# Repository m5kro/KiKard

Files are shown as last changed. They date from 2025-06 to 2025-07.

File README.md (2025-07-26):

# KiKard
Pronounced key card. KiKard is a usb microcontroller board with NFC read, write, and tag support. Built for Hack Club Highway. Not affiliated with KiCad (but do check them out).<br>
<br>
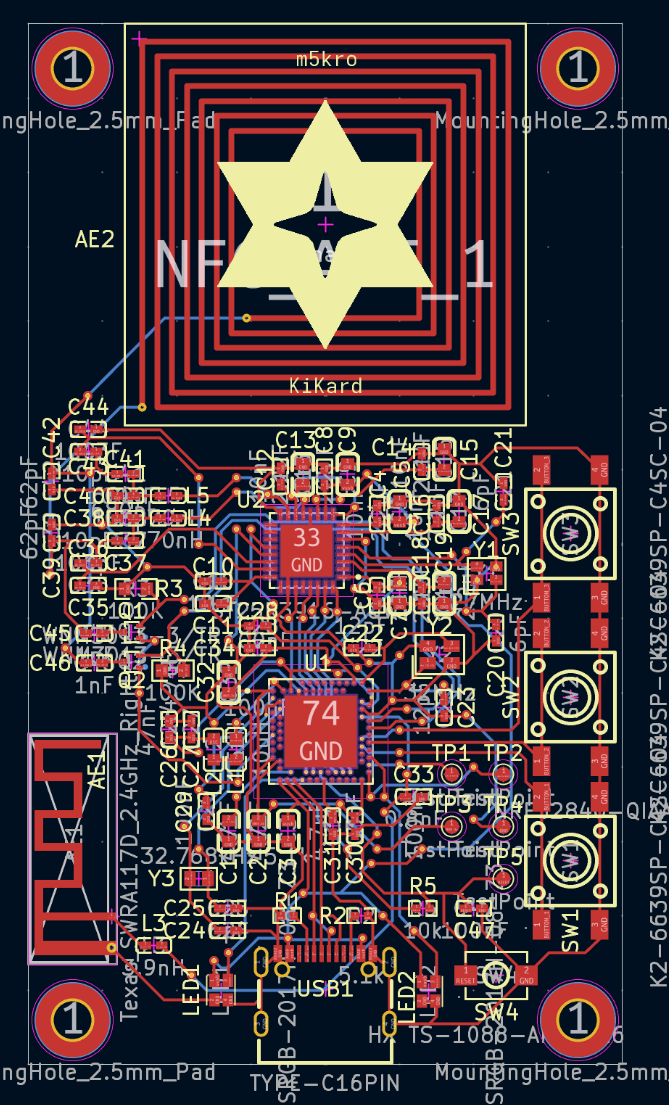
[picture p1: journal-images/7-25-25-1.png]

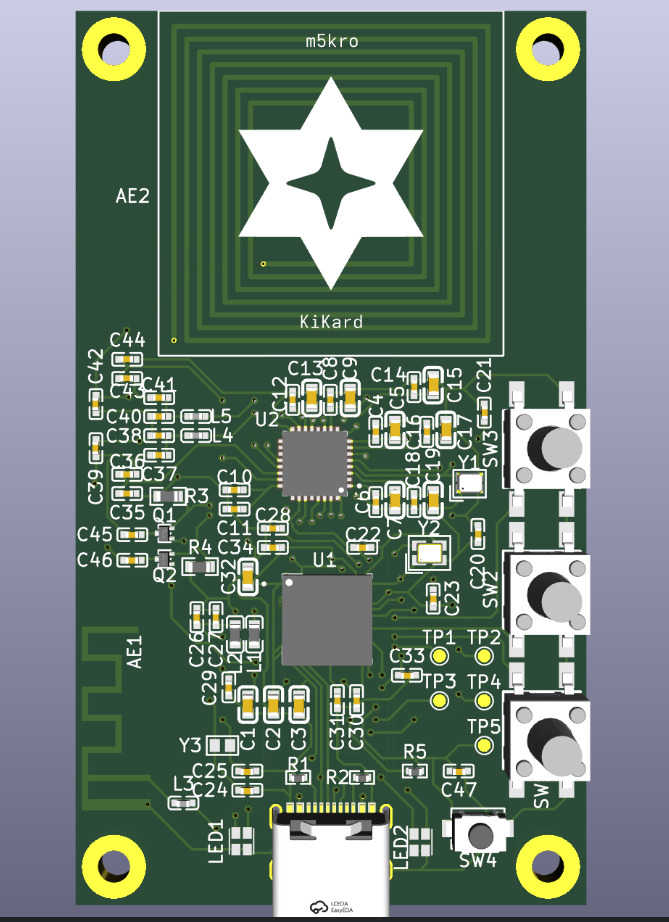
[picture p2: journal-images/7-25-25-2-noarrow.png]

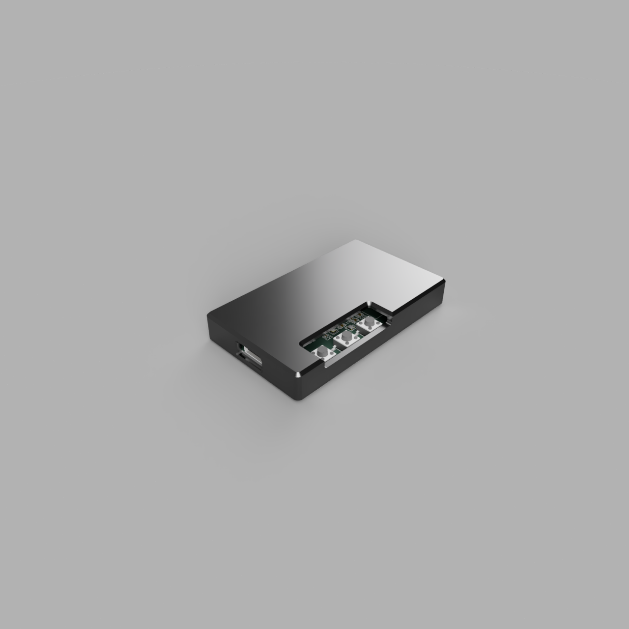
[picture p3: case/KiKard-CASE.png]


# What it does
KiKard is designed to read, write, and emulate NFC devices. This can be anything from simple link tags to complex keycards with custom communication standards. It can work independently or with a computer through BLE or USB.

# Why I built it
The goal of this project is to create a tool to assist me with my NFC application development learning. About a year ago, I wanted to make apps that utilize NFC, but I realized that most phones (most widespread implementation of NFC) are terrible for the development process as everything is very locked down. I did get a cheap PN532 reader from amazon and while it did help, it was still very lacking. Thus I decided to create KiKard to cover all the requirements needed by my other projects.

# Other Notes
Although the NRF has NFC support built in, it's only for tag mode, so a separate chip is needed for reading NFC.<br>
RGB LED 1 - Status led Green: just connected, Pink: reset/flashing, Blue: NRF52 tag mode, Yellow: ST25 read mode, Red: error<br>
RGB LED 2 - read/tag status Yellow: waiting, Blue: reading/emulating, Green: success, Red: error<br>
Button 1 - Read/emulate<br>
Button 2 - Switch between NRF52 and ST25<br>
Button 3 - Switch emulated tag (can save different cards on device)<br>
The DAPLINK is used to flash the NRF with a bootloader as it doesn't come with one by default. There are test pads on the board to connect.<br>
There are alot of extended parts as I needed high quality caps for the NFC antenna.<br>
Tariffs are making this project alot more expensive than it needs to be ;(

# Bom
| Item | Price |
| :-----: | :-----: |
| Custom PCB x5 | $4.00 |
| PCBA Setup | $8.00 |
| Stencil | $1.50 |
| PCB Parts x2| $20.07
| Extended Parts Fee | $81.00 |
| SMT Assembly | $1.86
| X-ray Inspection (required) | $3.14 |
| Nitrogen Reflow Soldering | $0.82 |
| Shipping | $28.85 |
| Customs | $66.22 |
| [DAPLINK](https://www.aliexpress.us/item/3256803753392042.html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) | $3.52 |
| JLCPCB special discount | -$2.00 |

**Total: $227.50**

# PCB Parts Bom (PER PCB)
Total PCB Parts: 71<br>
Total PCB Parts Price (per PCB): $8.7174
| Part | Designator | Quantity | Price per Unit | Total | JLCPCB/LCSC Part No. |
| :---: | :-----: | :-----: | :-----: | :-----: | :-----: |
| [NRF-52840-QIAA-R](https://jlcpcb.com/partdetail/NordicSemicon-NRF52840_QIAAR/C190794) | U1 | 1 | $4.0290 | $4.0290 | C190794 |
| [ST25R3916-AQWT](https://jlcpcb.com/partdetail/STMicroelectronics-ST25R3916AQWT/C2908147) | U2 | 1 | $3.3795 | $3.3795 | C2908147 |
| [WNM3013-3/TR](https://jlcpcb.com/partdetail/WILLSEMI_Will_Semicon-WNM3013_3TR/C239659) | Q1, Q2 | 2 | $0.0333 | $0.0667 | C239659 |
| [32MHz Crystal Oscillator](https://jlcpcb.com/partdetail/2777870-X201632MOB4SI/C2682773) | Y2 | 1 | $0.0890 | $0.0890 | C2682773 |
| [27MHz Crystal Oscillator](https://jlcpcb.com/partdetail/604049-XRCGB27M120F3M00R0/C576558) | Y1 | 1 | $0.1773 | $0.1773 | C576558 |
| [32KHz Crystal Oscillator](https://jlcpcb.com/partdetail/357119-X161032768KGD2SI/C383847) | Y3 | 1 | $0.3825 | $0.3825 | C383847 |
| [USB-C Port](https://jlcpcb.com/partdetail/SHOUHAN-TYPEC16PIN/C393939) | USB1 | 1 | $0.0642 | $0.0642 | C393939 |
| [RGBLED](https://jlcpcb.com/partdetail/ChauLight-ZSRGB_2017H_08Z3/C7497245) | LED1, LED2 | 2 | $0.0807 | $0.1614 | C7497245 |
| [Button](https://jlcpcb.com/partdetail/Korean_HropartsElec-K2_6639SP_C4SC04/C83206) | SW1, SW2, SW3 | 3 | $0.0380 | $0.1140 | C83206 |
| [Small Button](https://jlcpcb.com/partdetail/hanxia-HX_3x4x2_2P_25N/C36498961) | SW4 | 1 | $0.0299 | $0.0299 | C36498961 |
| [100k Ohm Resistor](https://jlcpcb.com/partdetail/YAGEO-RC0603FR07100KL/C14675) | R3, R4 | 2 | $0.0010 | $0.0020 | C14675 |
| [10k Ohm Resistor](https://jlcpcb.com/partdetail/26274-0402WGJ0103TCE/C25531) | R5 | 1 | $0.0004 | $0.0004 | C25531 |
| [5.1k Ohm Resistor](https://jlcpcb.com/partdetail/26684-0402WGJ0512TCE/C25941) | R1, R2 | 2 | $0.0004 | $0.0008 | C25941 |
| [4.7uF Capacitor](https://jlcpcb.com/partdetail/20375-CL10A475KO8NNNC/C19666) | C1, C2, C3, C32 | 4 | $0.0101 | $0.0404 | C19666 |
| [2.2uF Capacitor](https://jlcpcb.com/partdetail/1959-CL10A225KP8NNNC/C1607) | C5, C7, C9, C13, C15, C17, C19 | 7 | $0.0060 | $0.0420 | C1607 |
| [1uF Capacitor](https://jlcpcb.com/partdetail/15107-CL05A105KP5NNNC/C14445) | C11, C27 | 2 | $0.0016 | $0.0032 | C14445 |
| [100nF Capacitor](https://jlcpcb.com/partdetail/57421-0402B104K250NT/C56392) | C28, C29, C30, C31, C34, C47 | 6 |  $0.0011 |  $0.0066 | C56392 |
| [47nF Capacitor](https://jlcpcb.com/partdetail/83376-0402B473K500NT/C82219) | C26 | 1 | $0.0017 | $0.0017 | C82219 |
| [10nF Capacitor](https://jlcpcb.com/partdetail/1876-0402B103K500NT/C1524) | C4, C6, C8, C10, C12, C14, C16, C18 | 8 | $0.0010 | $0.0080 | C1524 |
| [1nF Capacitor](https://jlcpcb.com/partdetail/TDK-C1005C0G1E102JT000F/C343059) | C45, C46 | 2 | $0.0089 | $0.0178 | C343059 |
| [680pF Capacitor](https://jlcpcb.com/partdetail/1893-0402B681K500NT/C1541) | C38, C40 | 2 | $0.0011 | $0.0022 | C1541 |
| [100pF Capacitor](https://jlcpcb.com/partdetail/1898-0402CG101J500NT/C1546) | C35, C37, C41, C44 | 4 | $0.0089 | $0.0356 | C1546 |
| [62pF Capacitor](https://jlcpcb.com/partdetail/YAGEO-CC0402JRNPO9BN620/C281763) | C39, C42 | 2 | $0.0014 | $0.0028 | C281763 |
| [12pF Capacitor](https://jlcpcb.com/partdetail/1899-0402CG120J500NT/C1547) | C22, C23 | 2 | $0.0010 | $0.0020 | C1547 |
| [10pF Capacitor](https://jlcpcb.com/partdetail/1897-0402CG100J500NT/C1545) | C36, C43 | 2 | $0.0010 | $0.0020 | C1545 |
| [6pF Capacitor](https://jlcpcb.com/partdetail/1927-0402CG6R0C500NT/C1575) | C20, C21, C24, C25 | 4 | $0.0010 | $0.0040 | C1575 |
| [0.8pF Capacitor](https://jlcpcb.com/partdetail/41442-0402CG0R8C500NT/C40459) | C33 | 1 | $0.0013 | $0.0013 | C40459 |
| [10uH Inductor](https://jlcpcb.com/partdetail/Sunlord-MCL1608S100MT/C51942) | L1 | 1 | $0.0212 | $0.0212 | C51942 |
| [270nH Inductor](https://jlcpcb.com/partdetail/TDK-MLG1005SR27JT000/C76784) | L4, L5 | 2 | $0.0077 | $0.0154 | C76784 |
| [15nH Inductor](https://jlcpcb.com/partdetail/Sunlord-SDCL1608C15NJTDF/C23651) | L2 | 1 | $0.0106 | $0.0106 | C23651 |
| [3.9nH Inductor](https://jlcpcb.com/partdetail/Sunlord-SDCL1005C3N9STDF/C14033) | L3 | 1 | $0.0039 | $0.0039 | C14033 |

# Credit
[NRF-52840-QIAA-R schematic and footprint was aquired from snapeda](https://www.snapeda.com/parts/NRF52840-QIAA-R/Nordic%20Power/view-part/)<br>
[ST25R3916-AQWT schematic and footprint was aquired from snapeda](https://www.snapeda.com/parts/ST25R3916-AQWT/STMicroelectronics/view-part/)<br>
[NFC antenna footprint created using nfc antenna generator by nideri](https://github.com/nideri/nfc_antenna_generator)

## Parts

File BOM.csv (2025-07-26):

Item | Price | Link
Custom PCB x5 | 4 | /hardware
PCBA Setup | 8
Stencil | 1.5
PCB Parts x2 | 20.07 | /PCB-BOM.csv
Extended Parts Fee | 81
SMT Assembly | 1.86
X-ray Inspection (required) | 3.14
Nitrogen Reflow Soldering | 0.82
Shipping | 28.85
Customs | 66.22
DAPLINK | 3.52 | https://www.aliexpress.us/item/3256803753392042.html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
JLCPCB special discount | -2
Total | 227.50

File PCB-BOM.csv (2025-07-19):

Part | Designator | Quantity | Price per Unit | Total | JLCPCB/LCSC Part No. | Link
NRF-52840-QIAA-R | U1 | 1 | 4.0290 | 4.0290 | C190794 | https://jlcpcb.com/partdetail/NordicSemicon-NRF52840_QIAAR/C190794
ST25R3916-AQWT | U2 | 1 | 3.3795 | 3.3795 | C2908147 | https://jlcpcb.com/partdetail/STMicroelectronics-ST25R3916AQWT/C2908147
WNM3013-3/TR | Q1, Q2 | 2 | 0.0333 | 0.0667 | C239659 | https://jlcpcb.com/partdetail/WILLSEMI_Will_Semicon-WNM3013_3TR/C239659
32MHz Crystal Oscillator | Y2 | 1 | 0.0890 | 0.0890 | C2682773 | https://jlcpcb.com/partdetail/2777870-X201632MOB4SI/C2682773
27MHz Crystal Oscillator | Y1 | 1 | 0.1773 | 0.1773 | C576558 | https://jlcpcb.com/partdetail/604049-XRCGB27M120F3M00R0/C576558
32KHz Crystal Oscillator | Y3 | 1 | 0.3825 | 0.3825 | C383847 | https://jlcpcb.com/partdetail/357119-X161032768KGD2SI/C383847
USB-C Port | USB1 | 1 | 0.0642 | 0.0642 | C393939 | https://jlcpcb.com/partdetail/SHOUHAN-TYPEC16PIN/C393939
RGBLED | LED1, LED2 | 2 | 0.0807 | 0.1614 | C7497245 | https://jlcpcb.com/partdetail/ChauLight-ZSRGB_2017H_08Z3/C7497245
Button | SW1, SW2, SW3 | 3 | 0.0380 | 0.1140 | C83206 | https://jlcpcb.com/partdetail/Korean_HropartsElec-K2_6639SP_C4SC04/C83206
Small Button | SW4 | 1 | 0.0299 | 0.0299 | C36498961 | https://jlcpcb.com/partdetail/hanxia-HX_3x4x2_2P_25N/C36498961
100k Ohm Resistor | R3, R4 | 2 | 0.0010 | 0.0020 | C14675 | https://jlcpcb.com/partdetail/YAGEO-RC0603FR07100KL/C14675
10k Ohm Resistor | R5 | 1 | 0.0004 | 0.0004 | C25531 | https://jlcpcb.com/partdetail/26274-0402WGJ0103TCE/C25531
5.1k Ohm Resistor | R1, R2 | 2 | 0.0004 | 0.0008 | C25941 | https://jlcpcb.com/partdetail/26684-0402WGJ0512TCE/C25941
4.7uF Capacitor | C1, C2, C3, C32 | 4 | 0.0101 | 0.0404 | C19666 | https://jlcpcb.com/partdetail/20375-CL10A475KO8NNNC/C19666
2.2uF Capacitor | C5, C7, C9, C13, C15, C17, C19 | 7 | 0.0060 | 0.0420 | C1607 | https://jlcpcb.com/partdetail/1959-CL10A225KP8NNNC/C1607
1uF Capacitor | C11, C27 | 2 | 0.0016 | 0.0032 | C14445 | https://jlcpcb.com/partdetail/15107-CL05A105KP5NNNC/C14445
100nF Capacitor | C28, C29, C30, C31, C34, C47 | 6 | 0.0011 | 0.0066 | C56392 | https://jlcpcb.com/partdetail/57421-0402B104K250NT/C56392
47nF Capacitor | C26 | 1 | 0.0017 | 0.0017 | C82219 | https://jlcpcb.com/partdetail/83376-0402B473K500NT/C82219
10nF Capacitor | C4, C6, C8, C10, C12, C14, C16, C18 | 8 | 0.0010 | 0.0080 | C1524 | https://jlcpcb.com/partdetail/1876-0402B103K500NT/C1524
1nF Capacitor | C45, C46 | 2 | 0.0089 | 0.0178 | C343059 | https://jlcpcb.com/partdetail/TDK-C1005C0G1E102JT000F/C343059
680pF Capacitor | C38, C40 | 2 | 0.0011 | 0.0022 | C1541 | https://jlcpcb.com/partdetail/1893-0402B681K500NT/C1541
100pF Capacitor | C35, C37, C41, C44 | 4 | 0.0089 | 0.0356 | C1546 | https://jlcpcb.com/partdetail/1898-0402CG101J500NT/C1546
62pF Capacitor | C39, C42 | 2 | 0.0014 | 0.0028 | C281763 | https://jlcpcb.com/partdetail/YAGEO-CC0402JRNPO9BN620/C281763
12pF Capacitor | C22, C23 | 2 | 0.0010 | 0.0020 | C1547 | https://jlcpcb.com/partdetail/1899-0402CG120J500NT/C1547
10pF Capacitor | C36, C43 | 2 | 0.0010 | 0.0020 | C1545 | https://jlcpcb.com/partdetail/1897-0402CG100J500NT/C1545
6pF Capacitor | C20, C21, C24, C25 | 4 | 0.0010 | 0.0040 | C1575 | https://jlcpcb.com/partdetail/1927-0402CG6R0C500NT/C1575
0.8pF Capacitor | C33 | 1 | 0.0013 | 0.0013 | C40459 | https://jlcpcb.com/partdetail/41442-0402CG0R8C500NT/C40459
10uH Inductor | L1 | 1 | 0.0212 | 0.0212 | C51942 | https://jlcpcb.com/partdetail/Sunlord-MCL1608S100MT/C51942
270nH Inductor | L4, L5 | 2 | 0.0077 | 0.0154 | C76784 | https://jlcpcb.com/partdetail/TDK-MLG1005SR27JT000/C76784
15nH Inductor | L2 | 1 | 0.0106 | 0.0106 | C23651 | https://jlcpcb.com/partdetail/Sunlord-SDCL1608C15NJTDF/C23651
3.9nH Inductor | L3 | 1 | 0.0039 | 0.0039 | C14033 | https://jlcpcb.com/partdetail/Sunlord-SDCL1005C3N9STDF/C14033

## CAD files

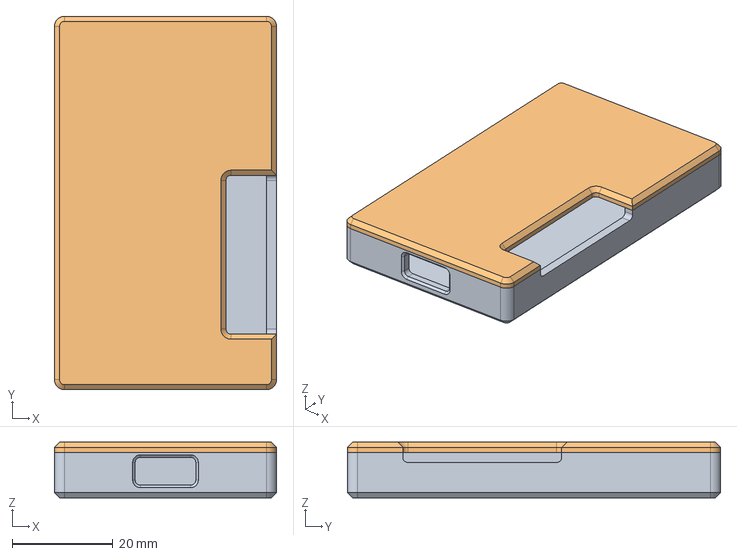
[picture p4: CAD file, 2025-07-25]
case/KiKard-Case.step
44.0 x 74.0 x 11.0 mm

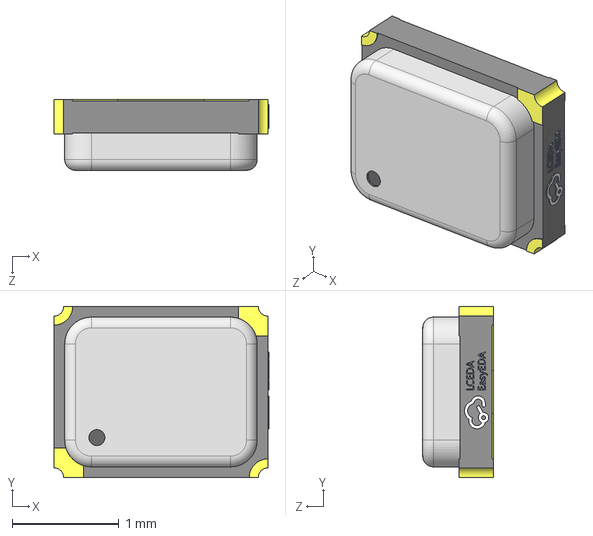
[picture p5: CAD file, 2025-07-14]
hardware/extra-symbols-footprints/3dshapes/CRYSTAL-SMD_4P-L2.0-W1.6-BL-B.step
2.01 x 1.60 x 0.66 mm

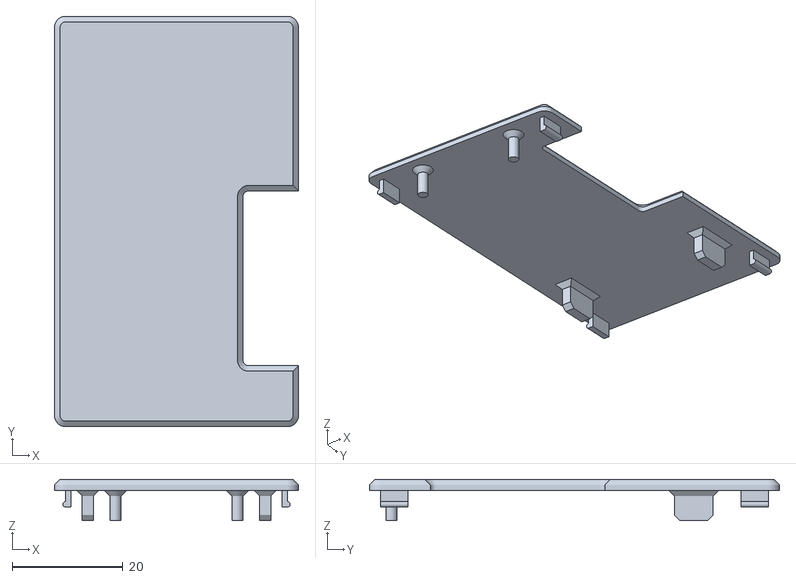
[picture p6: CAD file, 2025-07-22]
production/KiKard-Case-Top.stl
44.0 x 74.0 x 7.44

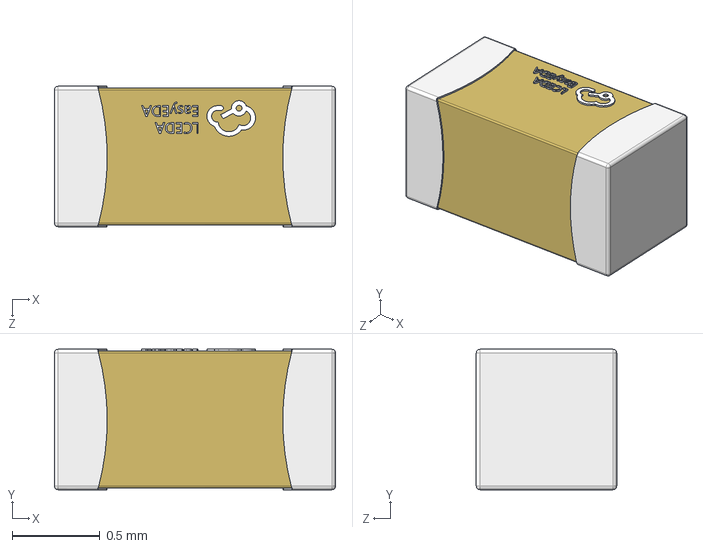
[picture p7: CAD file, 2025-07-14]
hardware/extra-symbols-footprints/3dshapes/C0603_L1.6-W0.8-H0.8.step
1.60 x 0.8 x 0.8 mm

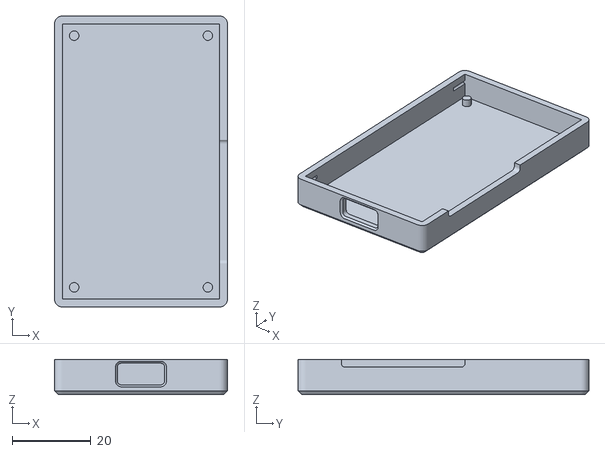
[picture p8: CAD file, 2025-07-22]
production/KiKard-Case-Base.stl
44.0 x 74.0 x 9.00

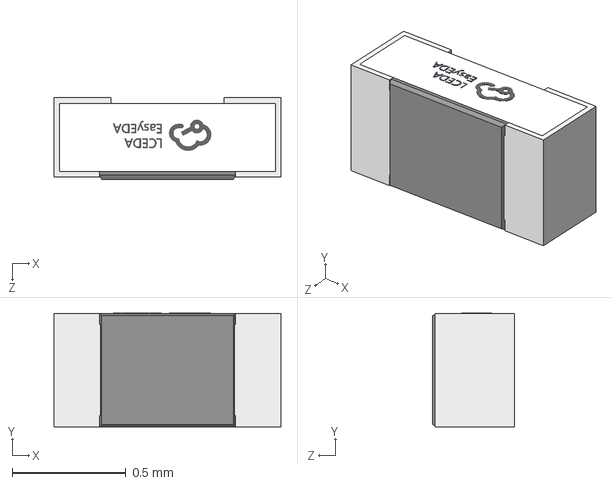
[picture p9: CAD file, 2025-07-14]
hardware/extra-symbols-footprints/3dshapes/R0402_L1.0-W0.5-H0.4.step
1.00 x 0.501 x 0.36 mm

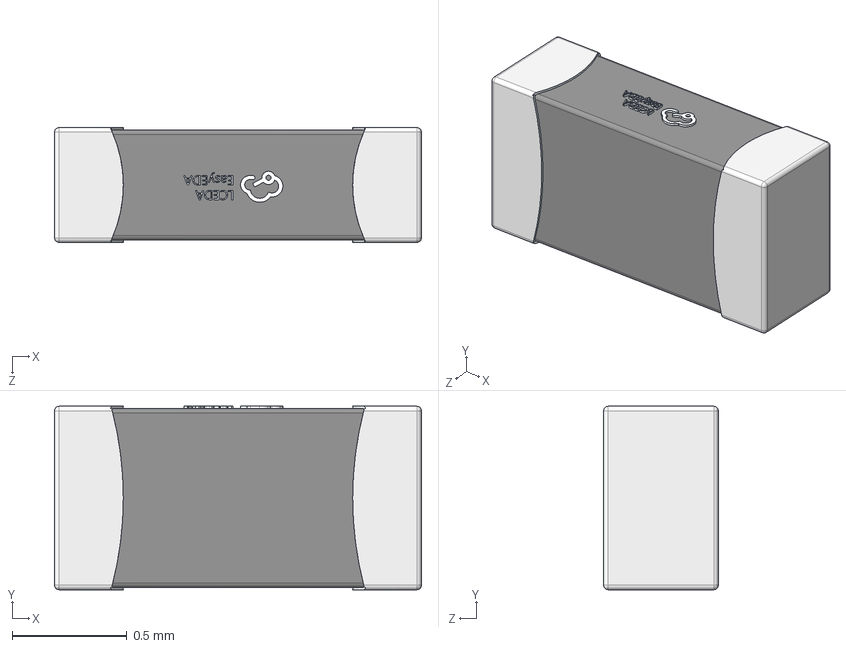
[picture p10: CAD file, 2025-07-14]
hardware/extra-symbols-footprints/3dshapes/L0603_L1.6-W0.8-H0.5_BEAD.step
1.60 x 0.8 x 0.5 mm

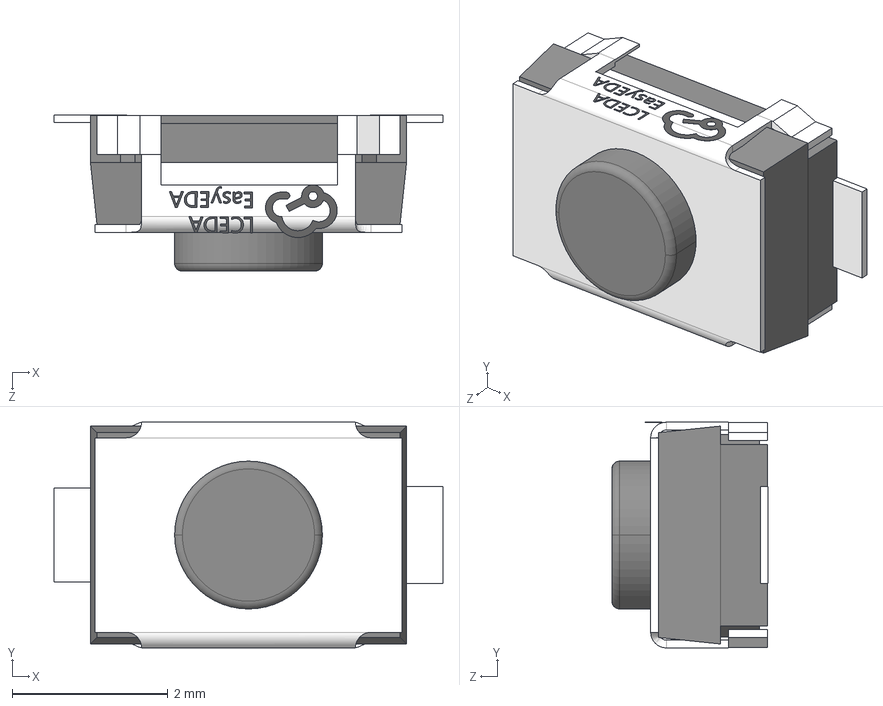
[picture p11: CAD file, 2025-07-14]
hardware/extra-symbols-footprints/3dshapes/SW-SMD_L4.0-W2.9-H2-LS5.0.step
5.00 x 2.90 x 2.01 mm

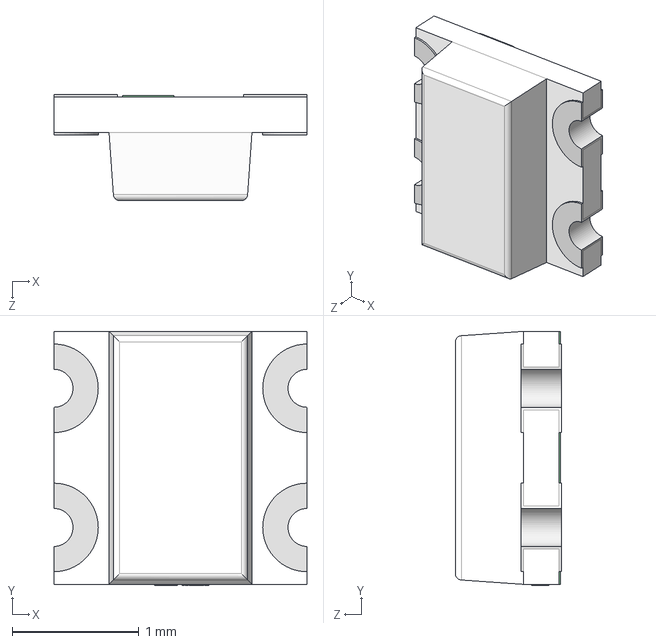
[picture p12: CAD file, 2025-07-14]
hardware/extra-symbols-footprints/3dshapes/LED-SMD_4P-L2.0-W2.0-H0.8-TL_WS2812B-2020.step
2.00 x 2.01 x 0.84 mm

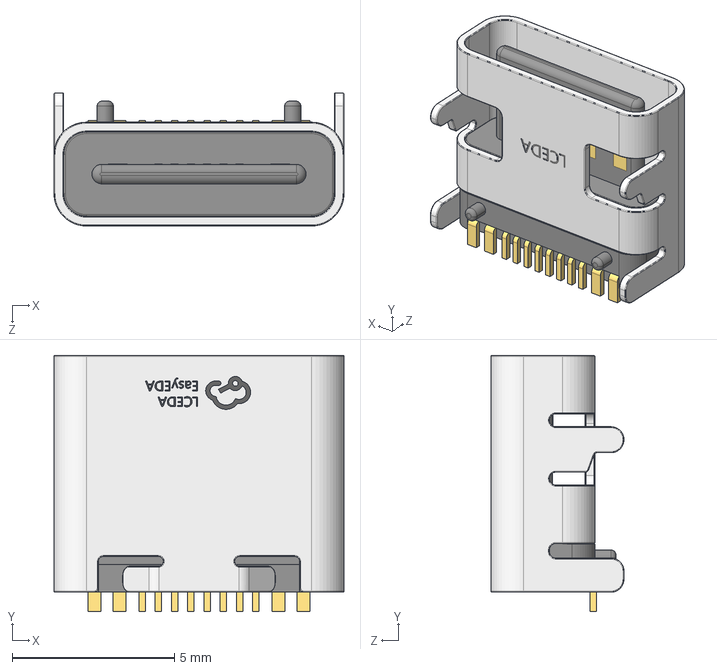
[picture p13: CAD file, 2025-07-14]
hardware/extra-symbols-footprints/3dshapes/USB-C-SMD_TYPE-C16PIN.step
8.94 x 7.90 x 4.10 mm

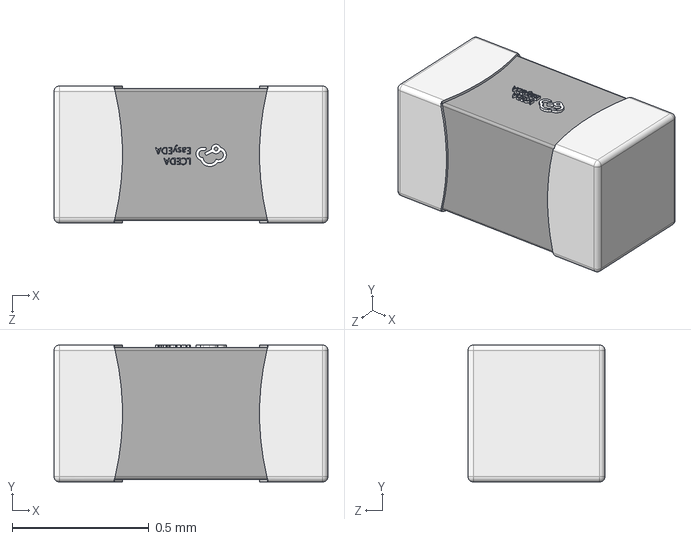
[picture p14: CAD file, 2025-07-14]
hardware/extra-symbols-footprints/3dshapes/L0402_L1.0-W0.5-H0.5_BEAD.step
1.00 x 0.5 x 0.5 mm

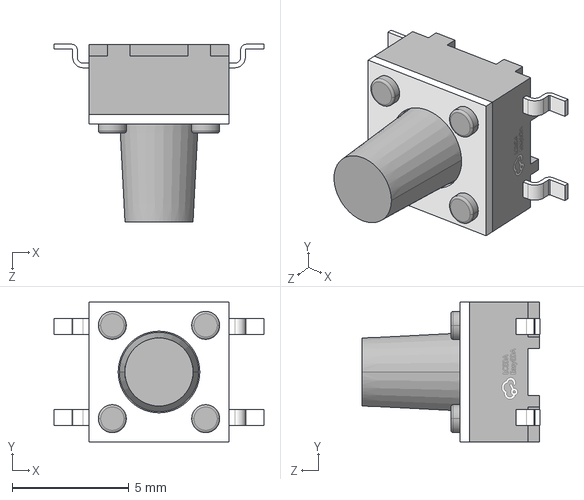
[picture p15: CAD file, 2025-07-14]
hardware/extra-symbols-footprints/3dshapes/KEY-SMD_4P-L6.0-W6.0-H8.0-P3.90-LS9.0.step
9.00 x 6.00 x 7.61 mm

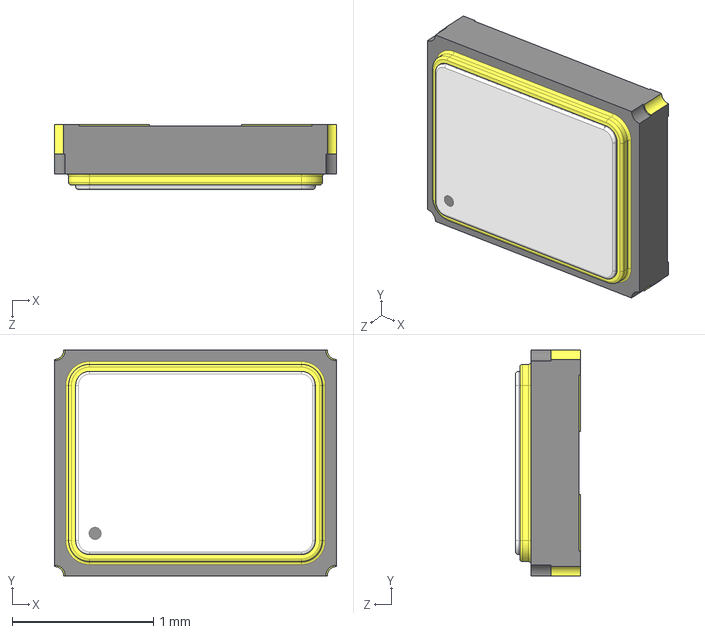
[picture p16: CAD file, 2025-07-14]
hardware/extra-symbols-footprints/3dshapes/CRYSTAL-SMD_4P-L2.0-W1.6-BL-2.step
2.00 x 1.60 x 0.46 mm

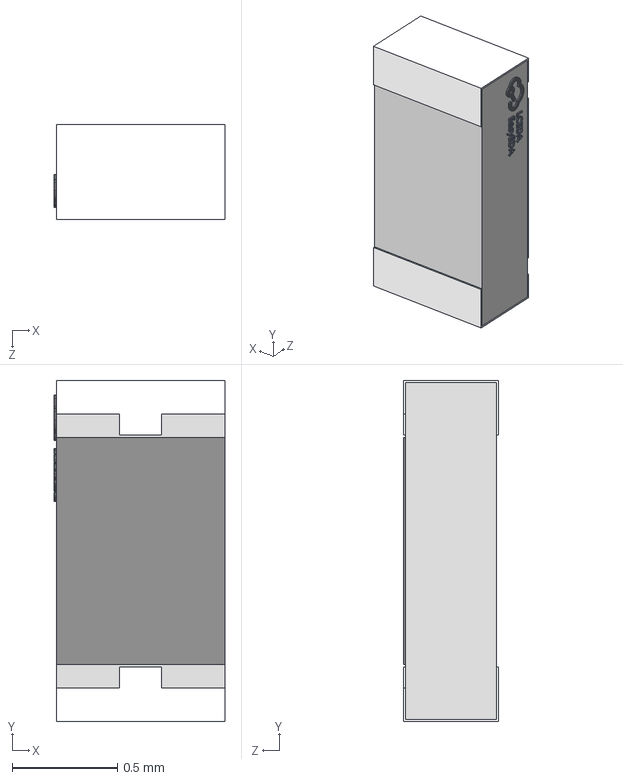
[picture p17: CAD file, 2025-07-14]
hardware/extra-symbols-footprints/3dshapes/R0603.step
0.81 x 1.62 x 0.45 mm

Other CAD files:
hardware/extra-symbols-footprints/3dshapes/C0402_L1.0-W0.5-H0.5.step
hardware/extra-symbols-footprints/3dshapes/SOT-723-3P_L1.2-W0.8-H0.6-LS1.2-P0.40.step
hardware/extra-symbols-footprints/3dshapes/ST25R3916-AQWT.step
hardware/extra-symbols-footprints/3dshapes/NRF52840-QIAA-R.step

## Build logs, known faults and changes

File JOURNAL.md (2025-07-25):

---
title: "KiKard"
author: "m5kro"
description: "A usb microcontroller board with NFC read, write, and tag support."
created_at: "2025-06-1"
---
# Total Time
50 hours

## 6/1/25 
Came up with the initial idea and some basic plans. I did research on the NRF-52 series and found out that it alone wasn't sufficient for what I wanted to build, so I needed a separate chip. After searching online, I found that the PN532 was a popular choice since it was cheap and widely available, but the PN533 might have more features. <br>
<br>
Since I settled on using the NRF-52840-QIAA-R as the main microcontroller I created a new KiCad project and imported the schematic and footprint.<br>
<br>
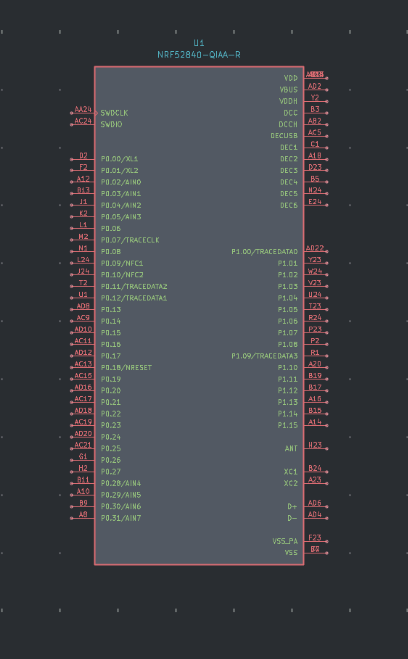
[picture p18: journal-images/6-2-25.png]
<br>
Screenshot of KiCad NRF-52840-QIAA-R schematic
<br>
<br>
**Time spent today: 2h**<br>
**Total time spent: 2h**
## 6/4/25
After further research and looking at what JLCPCB has, the ST25R3916-AQWT may be a better pick for the reader chip. It's cheaper than the PN532, a bit newer, and can do a bit more too. Although it is capable of tag emulation, it doesn't seem as capable as the NRF52, so a dual chip setup is still needed. <br>
<br>
A future problem I will need to deal with is the antenna setup. I will need a way to connect both chips to the antennas using a switching method so there isn't any interference.<br>
<br>
In KiCad, I imported the ST25R3916-AQWT symbol and schematic and connected up the NRF52 to a USB-C port.<br>
<br>
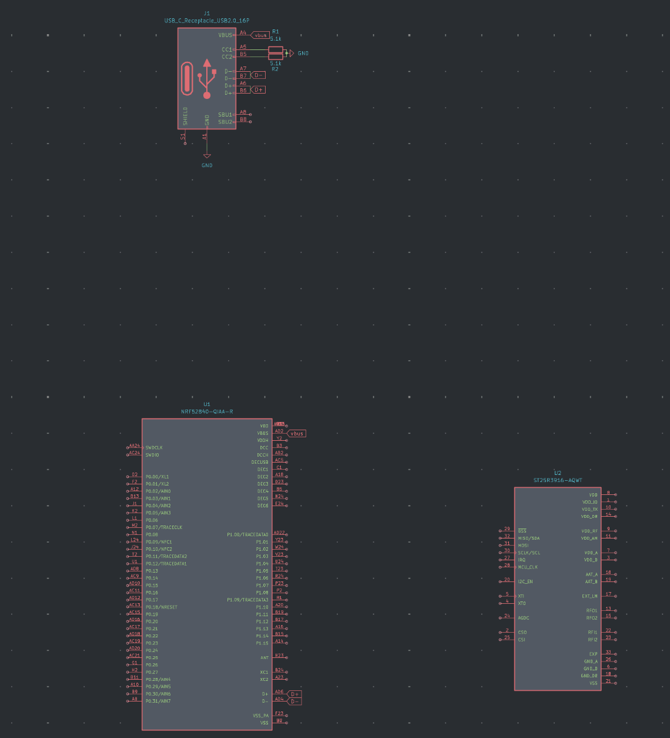
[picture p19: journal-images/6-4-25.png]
<br>
Screenshot of current KiCad progress<br>
<br>
**Time spent today: 2h**<br>
**Total time spent: 4h**
## 6/6/25
Spent today connecting up the ST25 to the NRF52 using SPI and making some other connections for the ST25. SPI was a bit confusing at first because the CS pin was labeled BSS, and I thought it was the CSO and CSI pins for a bit. Looking at diagrams online, most people are wiring up the ST25 with 5v on the VDD and VDDTX pins and 3.3v on the VDDIO pin, so I went with that (pulled 5v from usb and 3.3v from the NRF VDD output). The ST25 also needed a 27.12 MHz oscillator, so I used the XRCGB27M120F3M00R0 (terrible name). Finally, I decoupled everything on the ST25 (hopefully properly). <br>
<br>
The next update will probably be finishing up the wiring for the NRF52. After that I will work on figuring out the antenna setup. Also decided to ditch the battery.<br>
<br>
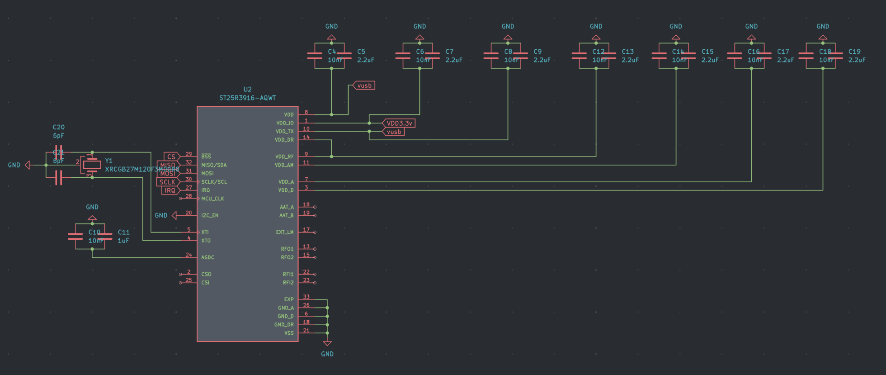
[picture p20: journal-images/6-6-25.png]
<br>
Screenshot of the current ST25 schematic (if you see any problems please message me, thanks)<br>
<br>
**Time spent today: 3h**<br>
**Total time spent: 7h**
## 6/29/25
Got back from vacation. Spent today wiring up the NRF52. I got all the decoupling, fixed the symbol, added a BLE antenna, and added the two oscillators (32 Mhz & 32.768 KHz). Everything looks very sketchy so far and I have no idea if it will work at all.<br>
<br>
I will try to get the NFC antennas figured out for the next update and also add the buttons.<br>
<br>
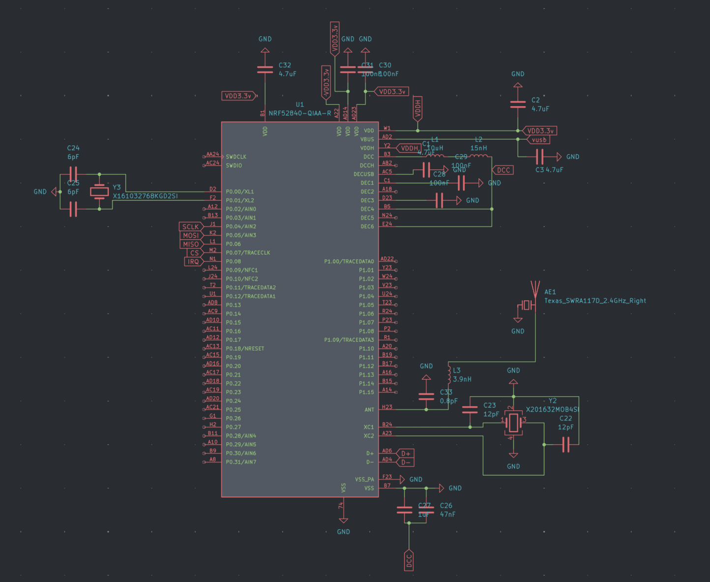
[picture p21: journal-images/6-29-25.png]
<br>
Screenshot of the almost completed NRF52 schematic (as usual please message me if you see any problems)<br>
<br>
**Time spent today: 5h**<br>
**Total time spent: 12h**
## 7/9/25
Spent today figuring out the NFC antenna. This took forever and really confused my brain, as I have no idea how RF works. After spending hours looking at documentation and performing calculations, I settled on a 25x25mm antenna with 7 turns, 0.4mm width traces, and 0.6mm spacing, to get around 1.37uH of inductance. 1.37uH is sort of a magic number because it simplifies all the tuning calculations for me. For the ST25 everything was already done for me since the flipper zero just so happens to use the same chip, and its antenna is also 1.37uH (thanks Flipper Zero team). The NRF52 was a bit harder since I needed to perform my own calculations, but thankfully, it came out to just around 200pF for each tuning capacitor.<br>
<br>
Next update I will get more of the schematic done and maybe figure out the mux (switching mechanism) for the antenna.<br>
<br>
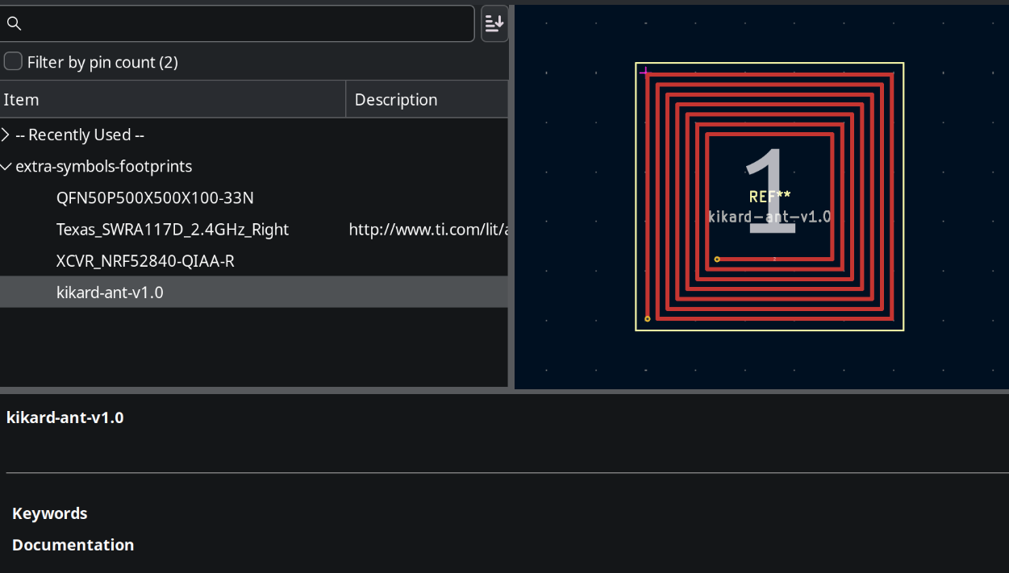
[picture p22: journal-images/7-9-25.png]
<br>
Screenshot of the NFC antenna footprint (created using: https://github.com/nideri/nfc_antenna_generator)<br>
<br>
**Time spent today: 5h**<br>
**Total time spent: 17h**
## 7/11/25
Finished up the NFC tuning for the ST25 today. I also sort of figured out a switching mechanism for the NRF52. It involves 2 mosfets to control when the NRF52 connects, and it attaches right onto the coil. It's an ugly solution and there's a good chance it doesn't work because the NRF52 can't quite be tuned in this setup. However, [some people online claim they have been able to get away with not tuning by using a MOLEX 1462360051 antenna](https://forum.seeedstudio.com/t/xiao-nrf52840-nfc-antenna-insights/277696), which happens to be 1.4uF (very close to my 1.37). I'll do more research later to see if this configuration actually works.<br>
<br>
Next update will (hopefully) be starting on the PCB layout.<br>
<br>
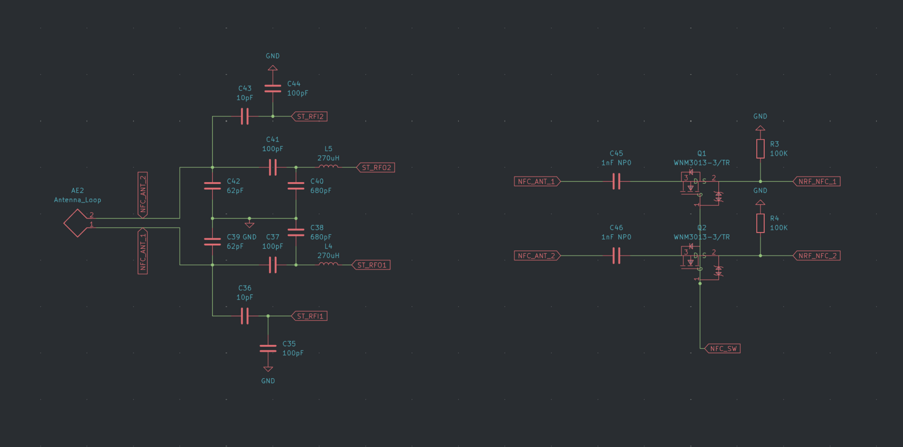
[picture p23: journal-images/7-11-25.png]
<br>
Screenshot of the terrible antenna switching mechanism and the ST25 tuning<br>
<br>
**Time spent today: 4h**<br>
**Total time spent: 21h**
## 7/14/25
Added the buttons, leds, and fixed some small stuff. I also spent most of the time finding footprints and actual parts on JLCPCB. The BOM took forever to do and I triple checked everything on the schemtics to make sure designing the PCB would be as smooth as possible.<br>
<br>
Next update I will be starting on the PCB.<br>
<br>
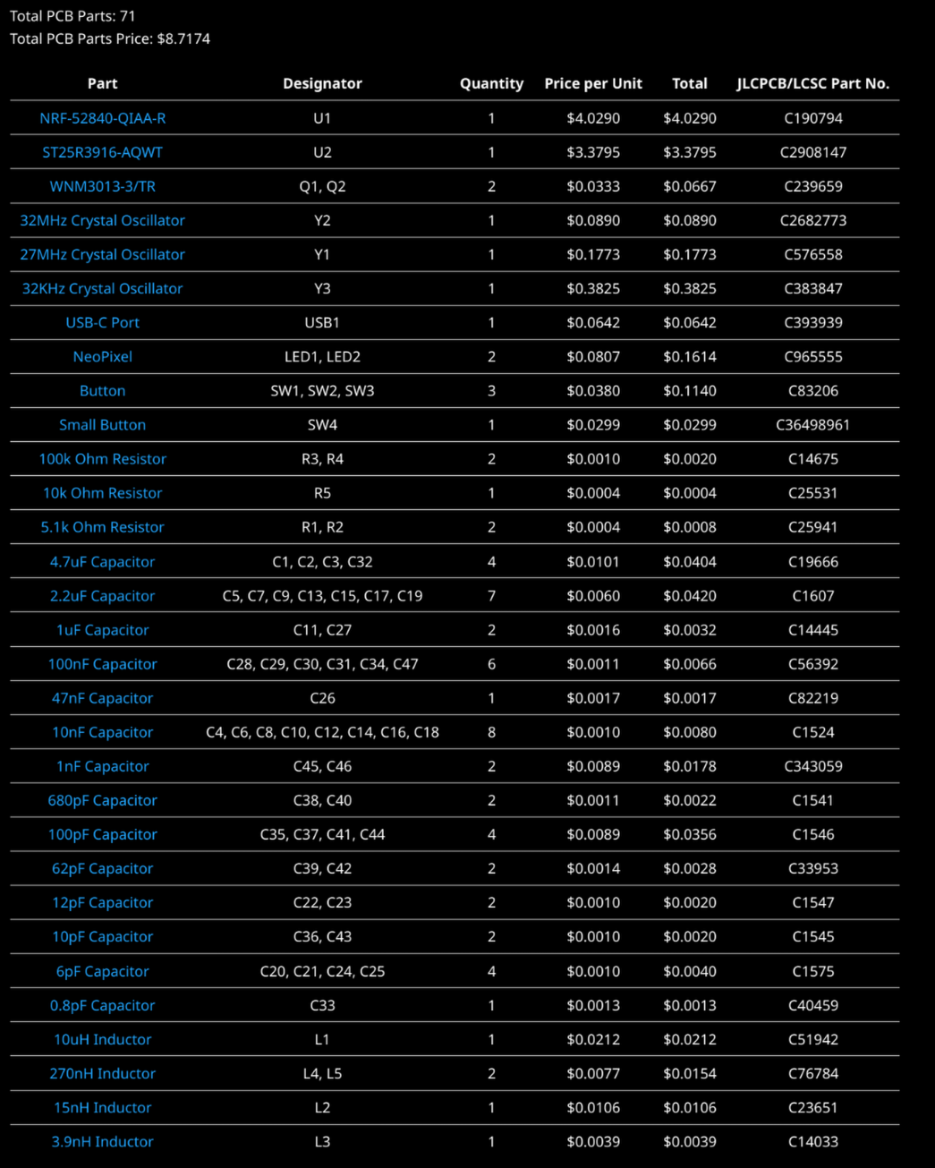
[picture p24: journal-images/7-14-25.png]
<br>
Screenshot of the superlong BOM<br>
<br>
**Time spent today: 4h**<br>
**Total time spent: 25h**
## 7/16/25
Started on the PCB! Currently have the usb and buttons wired up. Still working on getting the 3.3v output from the NRF52. I may need to expand the board in case I can't fit all the caps.<br>
<br>
Next update will be more of the PCB.<br>
<br>
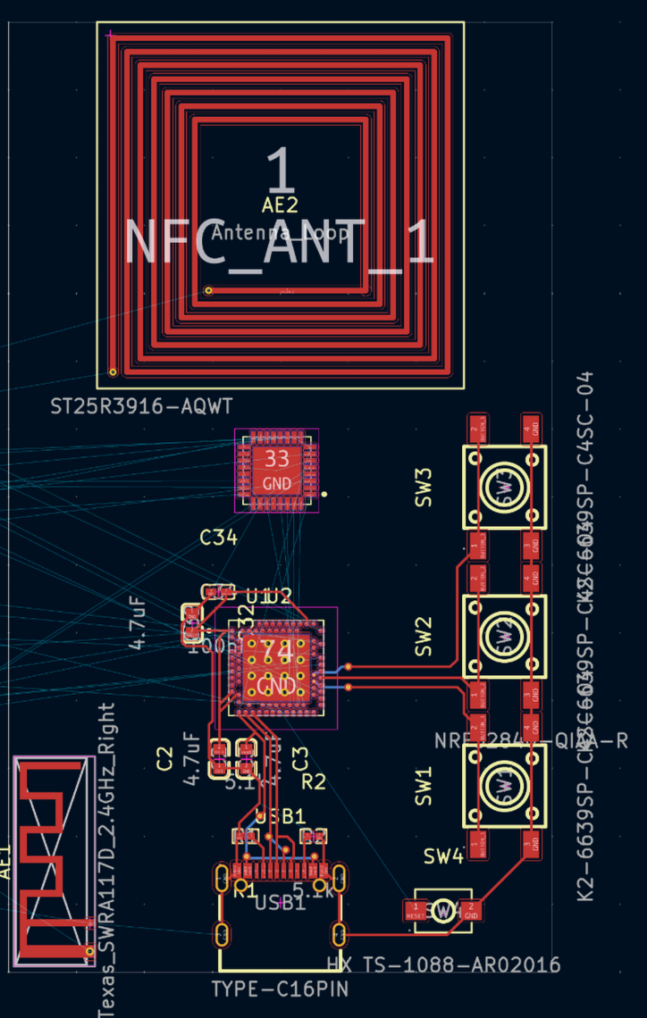
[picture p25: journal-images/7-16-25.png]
<br>
Screenshot of the current PCB progress<br>
<br>
**Time spent today: 3h**<br>
**Total time spent: 28h**
## 7/17/25
Spent today wiring up most of the NRF52, just have the NFC and SPI connections left to do. Some minor modifications had to be made to the schematic due to some of the GPIO pins on the NRF52 being "slow speed". I'm also worried about the spacing for the ST25 as all the caps need to be squeezed into a sort of line.<br>
<br>
Next update will (hopfully) be the finished PCB.<br>
<br>
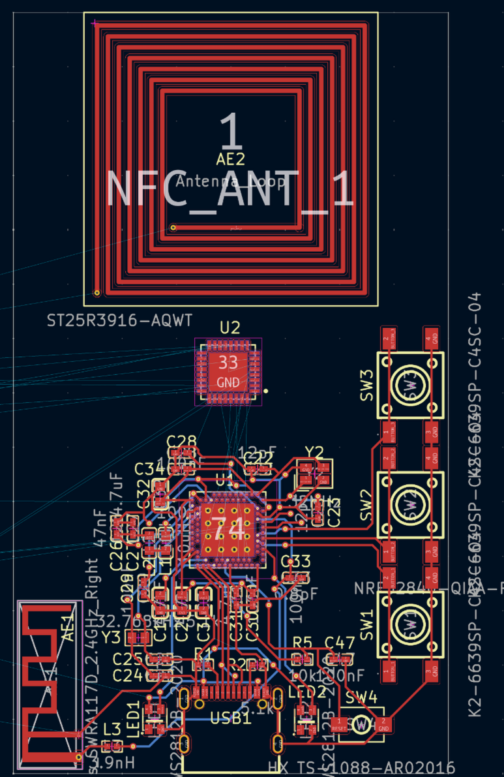
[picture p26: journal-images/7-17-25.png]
<br>
Screenshot of the current PCB progress<br>
<br>
**Time spent today: 5h**<br>
**Total time spent: 33h**
## 7/18/25
Finished the PCB! I also generated the gerbers and position files to see how much it would cost on JLCPCB. I ran into some issues initially where the vias wern't showing up but I fixed it by reading JLCPCB's documentation. I didn't realize some parts were standard PCBA only so I had to switch them out for different ones (the RGBLEDs and 62pF caps). I also found out about the "extended" parts fee and that really hurt to look at. I can still get the 5 boards just under $150 though, so it'll be around $30 per board. There's not much left to do but create a case and write some initial test code.<br>
<br>
Next update will be the case and some code.<br>
<br>
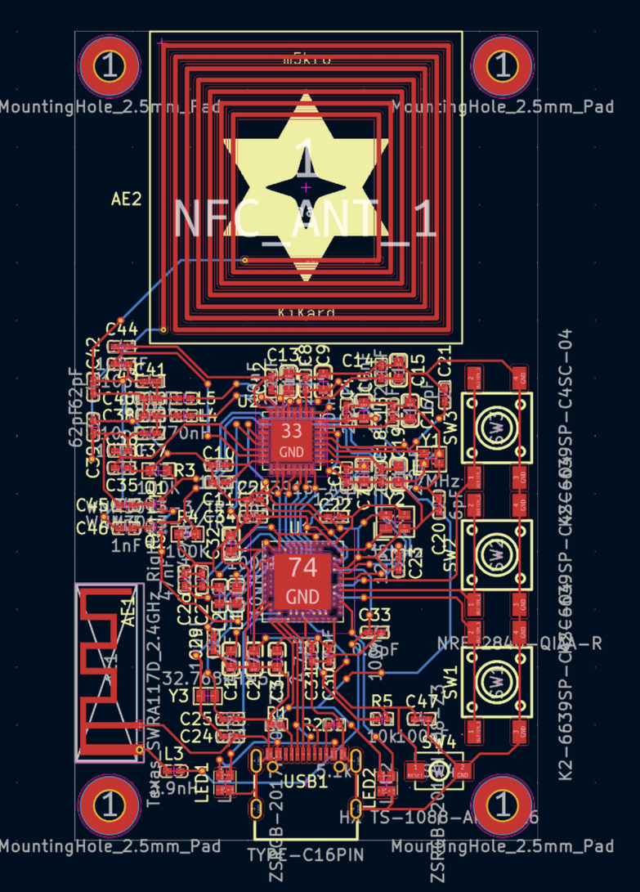
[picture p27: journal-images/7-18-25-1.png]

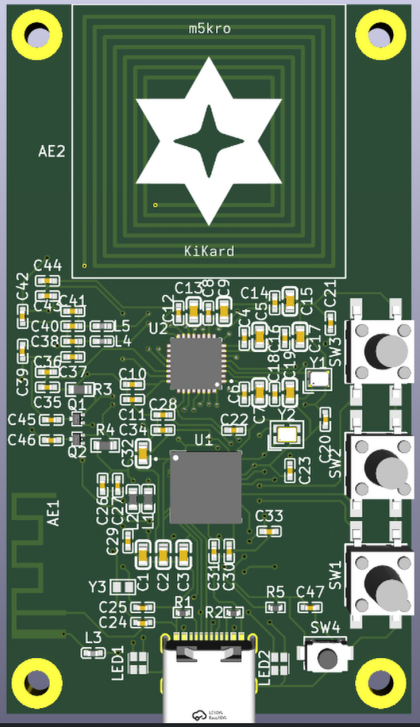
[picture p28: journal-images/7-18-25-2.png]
<br>
Screenshot of the final PCB layout and 3D render<br>
<br>
**Time spent today: 7h**<br>
**Total time spent: 40h**
## 7/21/25
Created a case for the PCB. It's got curved and chamfered edges to be comfortable to hold and nice to look at. Instead of screw holes I opted to design some internal clips so it's much easier to assemble and take apart. The buttons on the side are exposed, mostly because I think it looks good but also because I was too lazy to design extensions in the case. There was a small issue where the button hight was incorrect which I had to manually fix but otherwise everything looks ok.<br>
<br>
I'll start working on the test code next.<br>
<br>

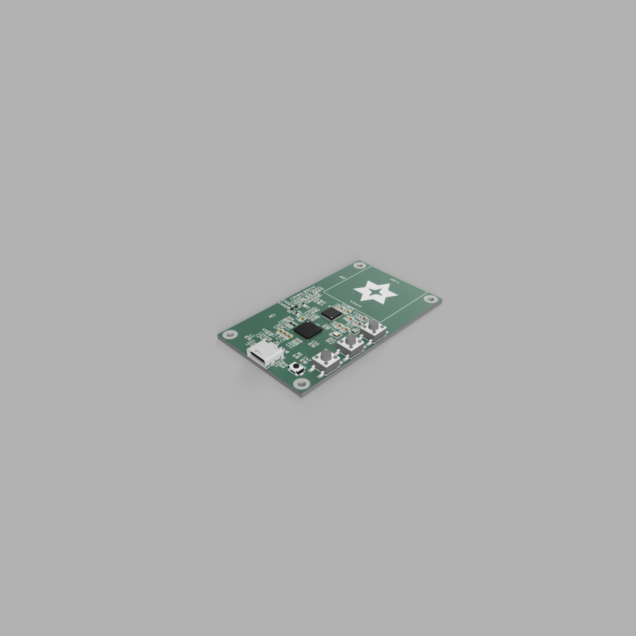
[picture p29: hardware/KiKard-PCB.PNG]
<br>
Screenshot of the rendered case and fixed PCB<br>
<br>
**Time spent today: 5h**<br>
**Total time spent: 45h**
## 7/25/25
Created a test application today! During my reseach for the NRF connect SDK I found out that the chip does not come with a bootloader by default. Because of this, I needed to add some testpads onto the board and I also need to buy a flasher to add the bootloader. This thankfully wans't too hard as there was just enough space to squeeze in the pads without moving any existing components. I also learned about how to use the SDK and exentions to compile a uf2 firmware file. It should now be ready to be shown off at the pitstop and submitted!<br>
<br>
Next update I will hopefully have the boards.<br>
<br>

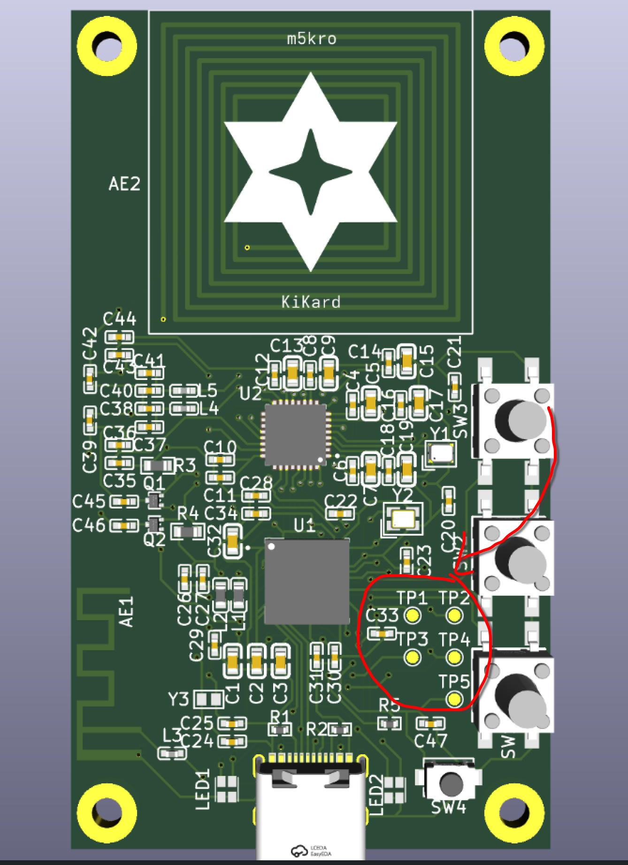
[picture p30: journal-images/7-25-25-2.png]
<br>
Screenshot of updated board (new testpads are marked)<br>
<br>
**Time spent toay: 5h**<br>
**Total time spent: 50h**

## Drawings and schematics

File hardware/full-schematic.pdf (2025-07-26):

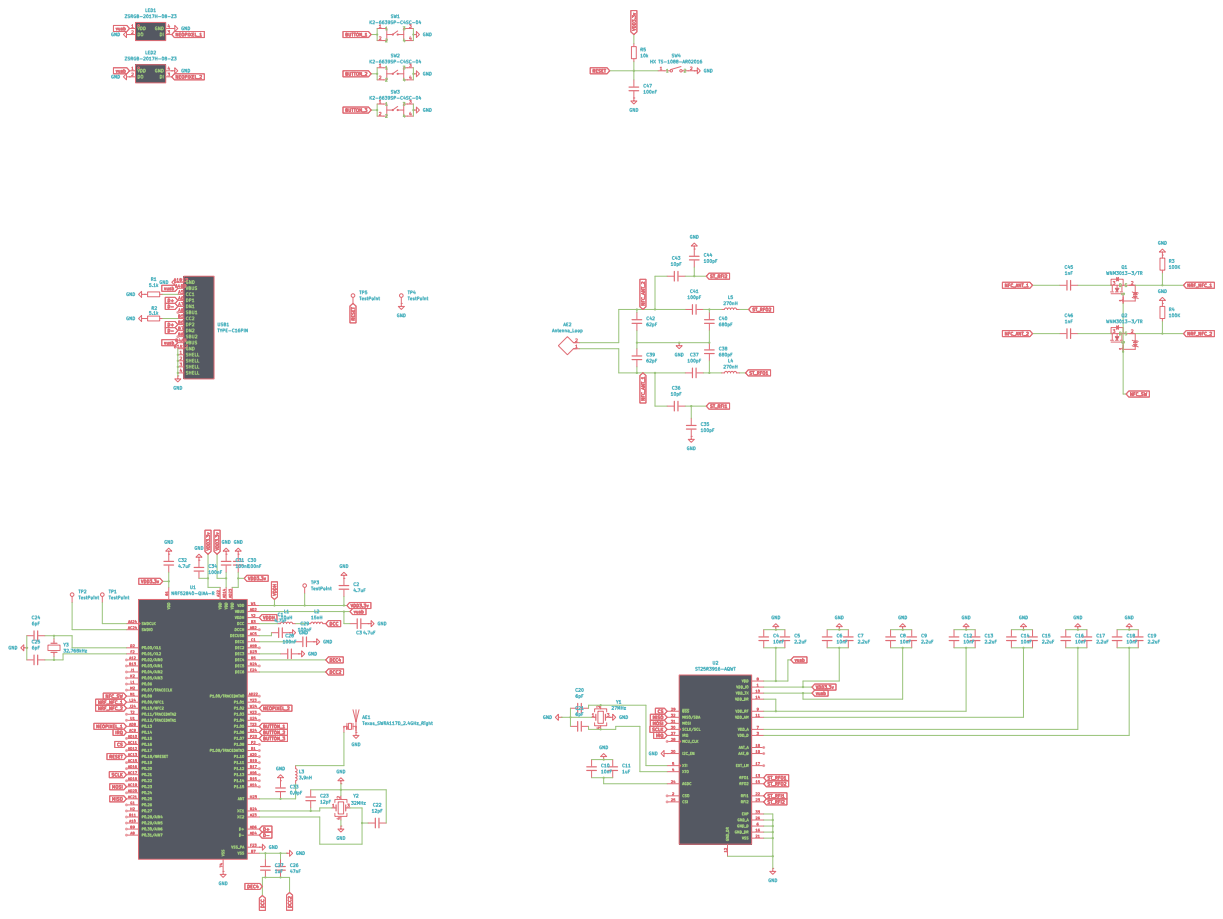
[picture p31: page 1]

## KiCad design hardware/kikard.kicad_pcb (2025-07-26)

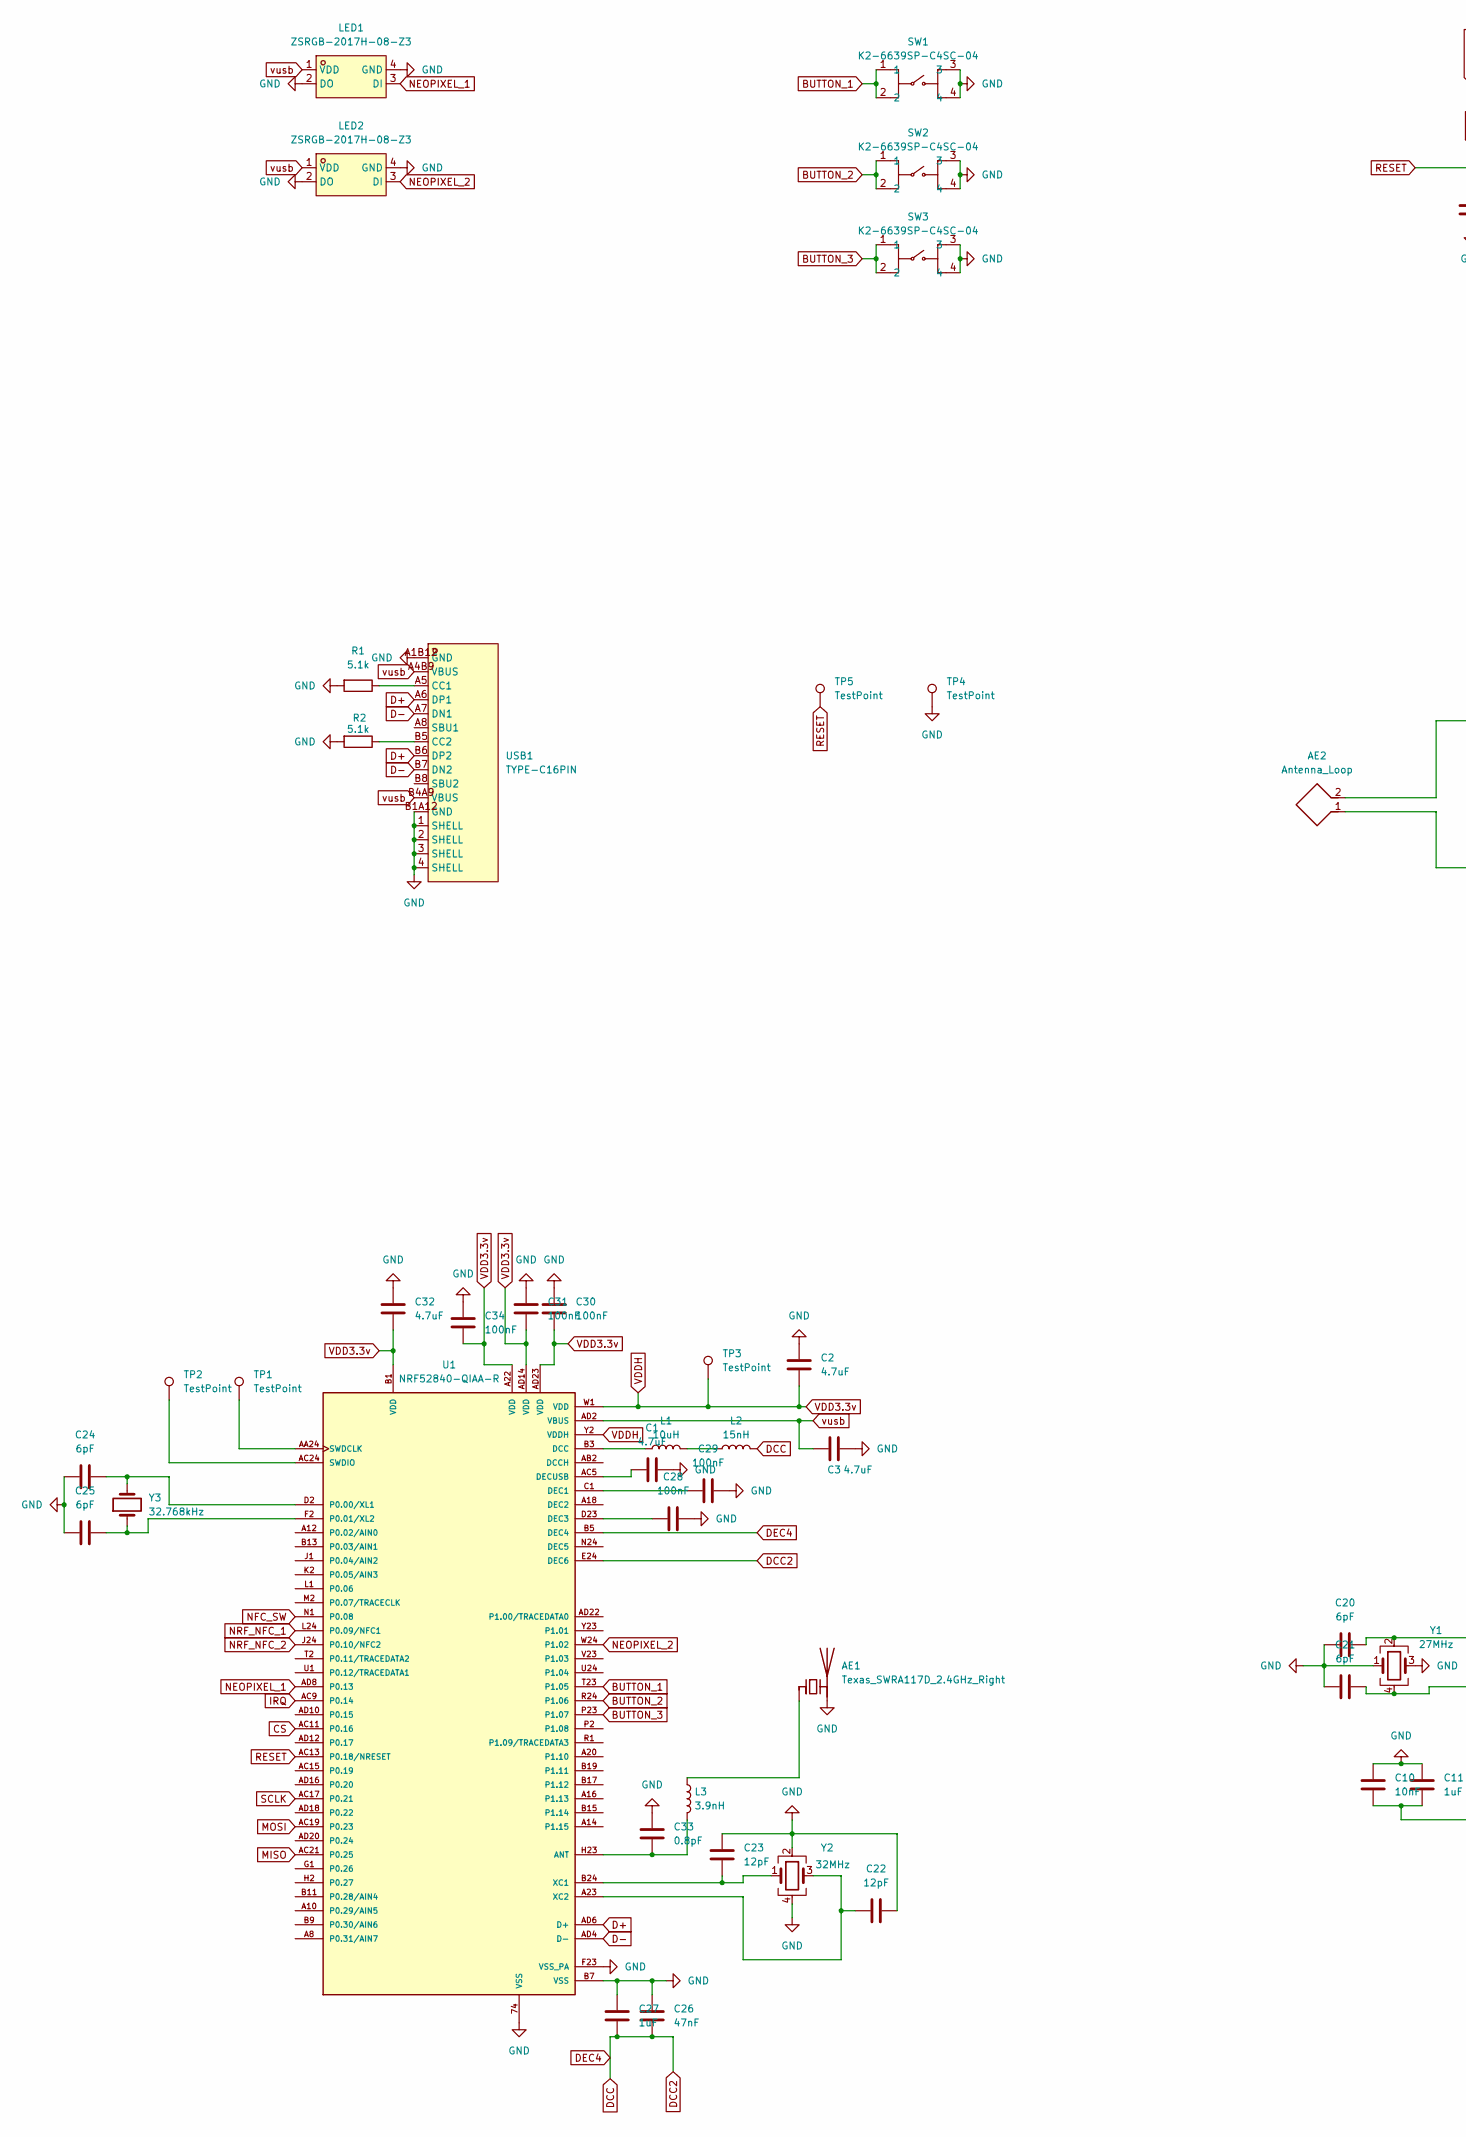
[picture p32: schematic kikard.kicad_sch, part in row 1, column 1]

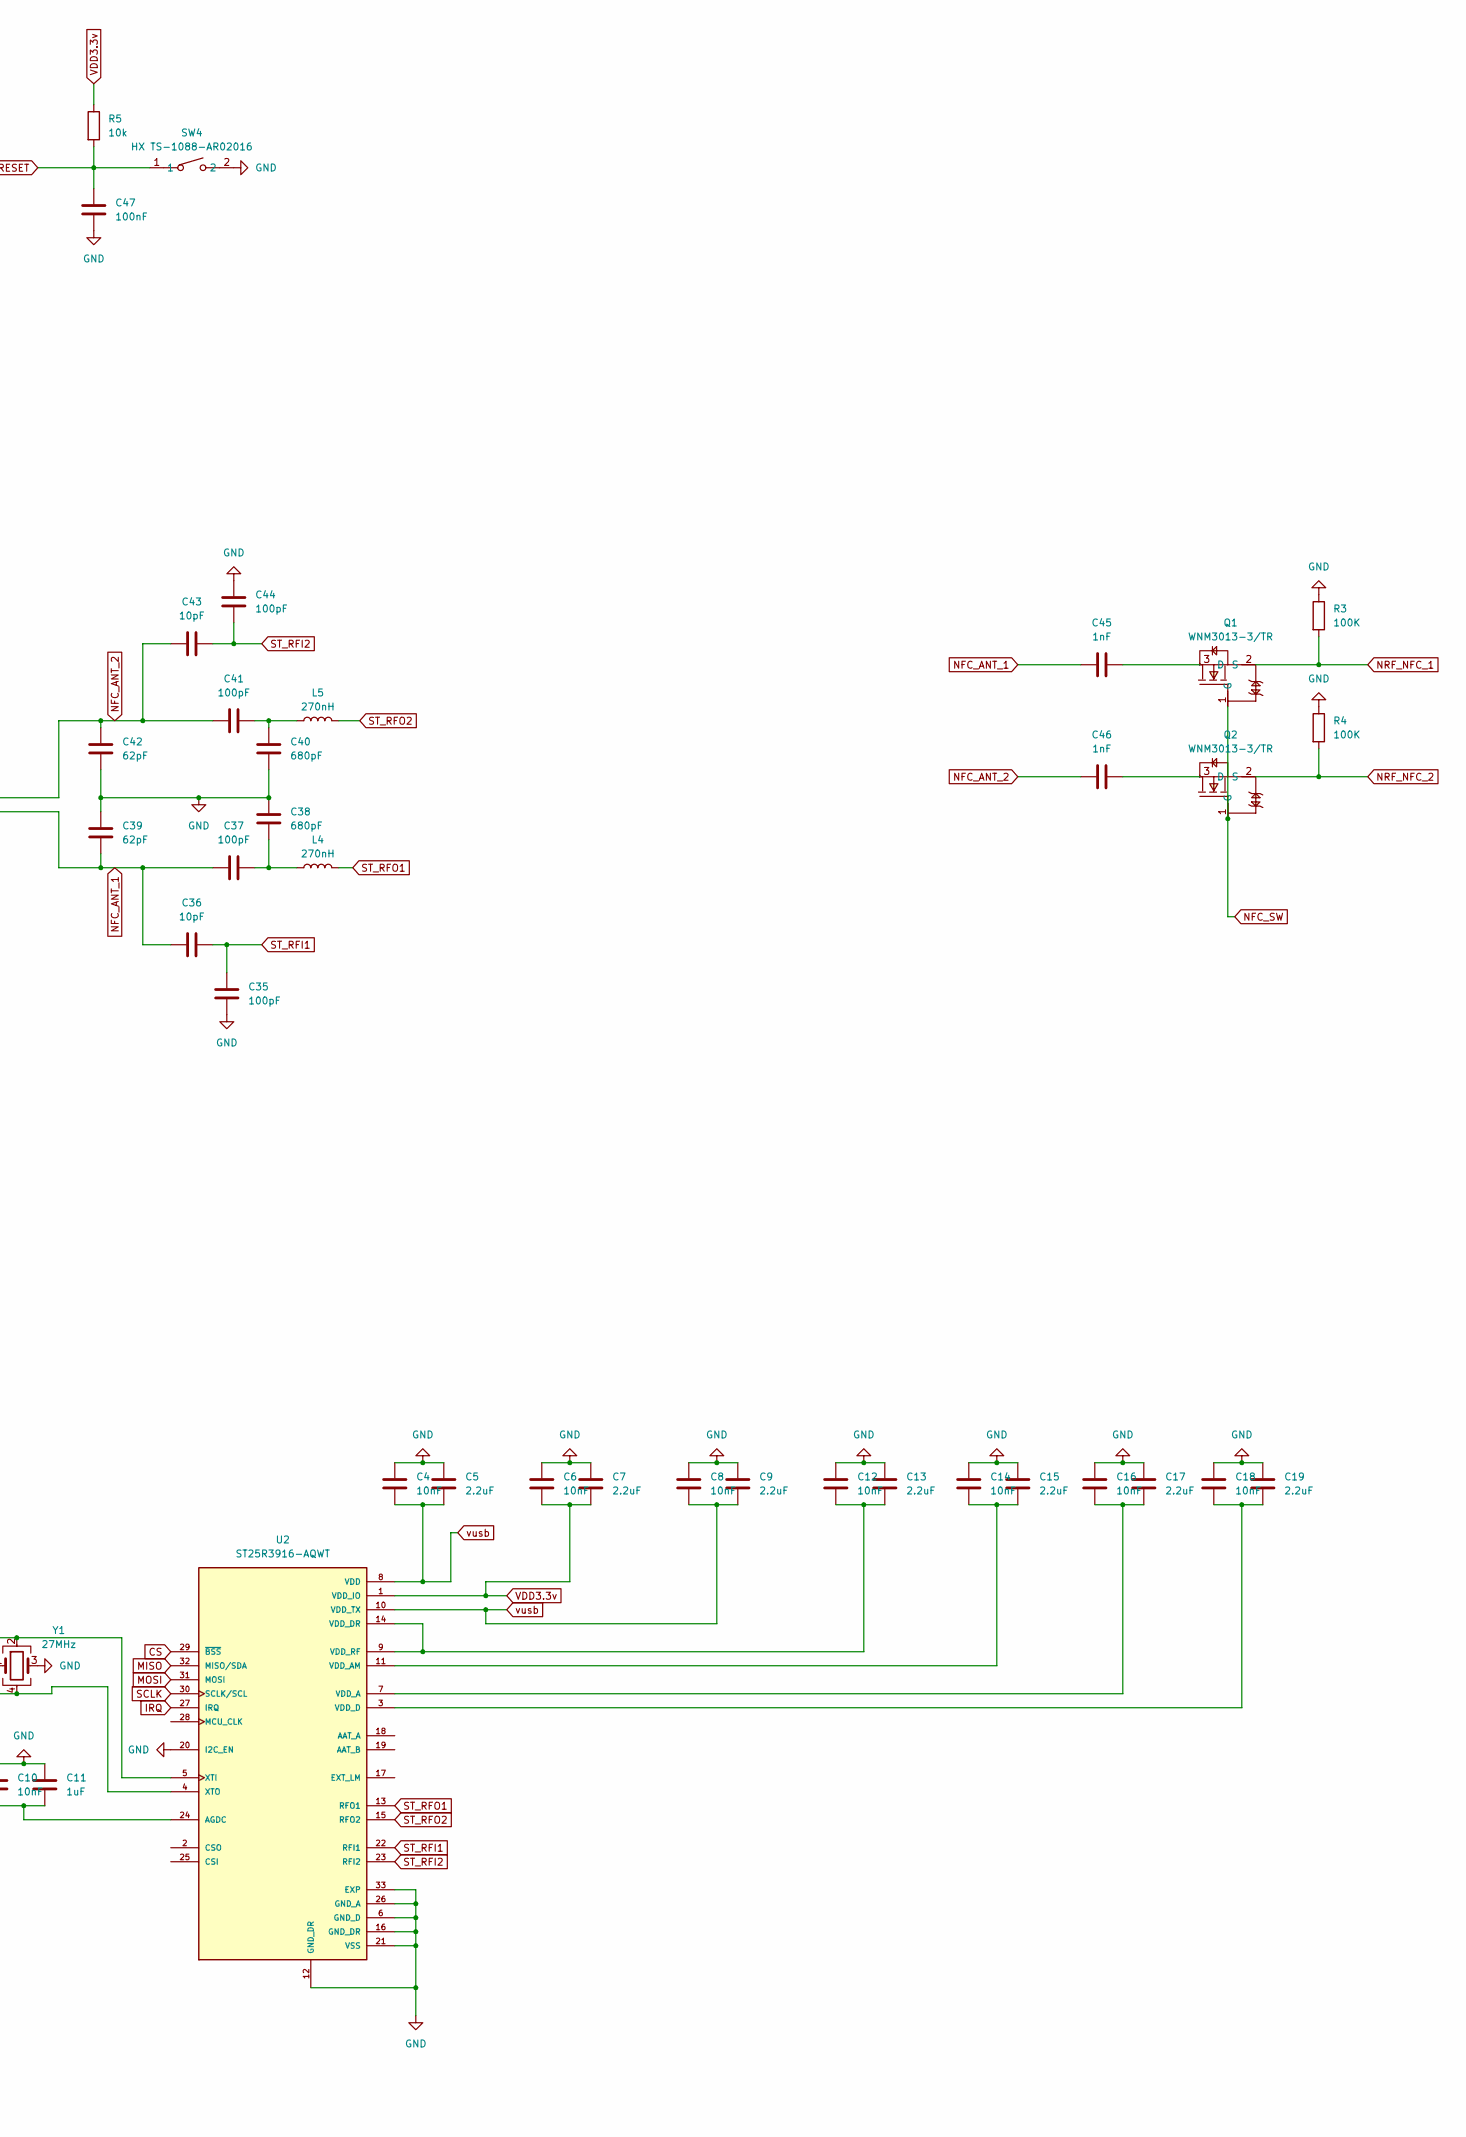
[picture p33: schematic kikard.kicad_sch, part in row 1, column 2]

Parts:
AE1: Texas_SWRA117D_2.4GHz_Right
AE2: Antenna_Loop; kikard-ant-v1.0
C1, C2, C3, C32: 4.7uF; C0603
C4, C6, C8, C10, C12, C14, C16, C18: 10nF; C0402
C5, C7, C9, C13, C15, C17, C19: 2.2uF; C0603
C11, C27: 1uF; C0402
C20, C21, C24, C25: 6pF; C0402
C22, C23: 12pF; C0402
C26: 47nF; C0402
C28, C29, C30, C31, C34, C47: 100nF; C0402
C33: 0.8pF; C0402
C35, C37, C41, C44: 100pF; C0402
C36, C43: 10pF; C0402
C38, C40: 680pF; C0402
C39, C42: 62pF; C0402
C45, C46: 1nF; C0402
L1: 10uH; L0603
L2: 15nH; L0603
L3: 3.9nH; L0402
L4, L5: 270nH; L0402
LED1, LED2: ZSRGB-2017H-08-Z3; LED-SMD_4P-L2.0-W1.8-P0.90_XGM-S0807RGB; LCSC Part C7497245
Q1, Q2: WNM3013-3/TR; SOT-723_L1.2-W0.8-P0.40-LS1.2-BR; LCSC Part C239659
R1, R2: 5.1k; R0402
R3, R4: 100K; R0603
R5: 10k; R0402
SW1, SW2, SW3: K2-6639SP-C4SC-04; KEY-SMD_4P-L6.0-W6.0-P3.90-LS9.0; LCSC Part C83206
SW4: HX TS-1088-AR02016; SW-SMD_L4.0-W2.9-LS5.0; LCSC Part C36498961
TP1, TP2, TP3, TP4, TP5: TestPoint; TestPoint_Pad_D1.0mm
U1: NRF52840-QIAA-R; XCVR_NRF52840-QIAA-R; PARTREV v1.1
U2: ST25R3916-AQWT; QFN50P500X500X100-33N; PARTREV 4
USB1: TYPE-C16PIN; USB-C-SMD_TYPE-C16PIN; LCSC Part C393939
Y1: 27MHz; CRYSTAL-SMD_4P-L2.0-W1.6-BL-B
Y2: 32MHz; CRYSTAL-SMD_4P-L2.0-W1.6-BL-2
Y3: 32.768kHz; OSC-SMD_L1.6-W1.0

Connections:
BUTTON_1: SW1.1, SW1.2, U1.T23 (P1.05)
BUTTON_2: SW2.1, SW2.2, U1.R24 (P1.06)
BUTTON_3: SW3.1, SW3.2, U1.P23 (P1.07)
CS: U1.AC11 (P0.16), U2.29 (~BSS)
D+: U1.AD6 (D+), USB1.A6 (DP1), USB1.B6 (DP2)
D-: U1.AD4 (D-), USB1.A7 (DN1), USB1.B7 (DN2)
DCC: C26.2, C27.2, L2.2, U1.B5 (DEC4), U1.E24 (DEC6)
GND: AE1.2 (PCB_Trace), C1.1, C2.1, C3.2, C4.1, C5.1, C6.1, C7.1, C8.1, C9.1, C10.1, C11.1, C12.1, C13.1, C14.1, C15.1, C16.1, C17.1, C18.1, C19.1, C20.1, C21.1, C22.2, C23.2, C24.1, C25.1, C26.1, C27.1, C28.2, C29.2, C30.1, C31.1, C32.1, C33.1, C34.1, C35.2, C38.1, C39.1, C40.2, C42.2, C44.1, C47.2, LED1.2 (DO), LED1.4 (GND), LED2.2 (DO), LED2.4 (GND), R1.2, R2.2, R3.1, R4.1, SW1.3, SW1.4, SW2.3, SW2.4, SW3.3, SW3.4, SW4.2, TP4.1, U1.74 (VSS), U1.B7 (VSS), U1.F23 (VSS_PA), U2.6 (GND_D), U2.12 (GND_DR), U2.16 (GND_DR), U2.20 (I2C_EN), U2.21 (VSS), U2.26 (GND_A), U2.33 (EXP), USB1.1 (SHELL), USB1.2 (SHELL), USB1.3 (SHELL), USB1.4 (SHELL), USB1.A1B12 (GND), USB1.B1A12 (GND), Y1.1, Y1.3, Y2.2, Y2.4
IRQ: U1.AC9 (P0.14), U2.27 (IRQ)
MISO: U1.AC21 (P0.25), U2.32 (MISO/SDA)
MOSI: U1.AC19 (P0.23), U2.31 (MOSI)
NEOPIXEL_1: LED1.3 (DI), U1.AD8 (P0.13)
NEOPIXEL_2: LED2.3 (DI), U1.W24 (P1.02)
NFC_ANT_1: AE2.1, C36.1, C37.1, C39.2, C45.1
NFC_ANT_2: AE2.2, C41.1, C42.1, C43.1, C46.1
NFC_SW: Q1.1 (G), Q2.1 (G), U1.N1 (P0.08)
NRF_NFC_1: Q1.2 (S), R3.2, U1.L24 (P0.09/NFC1)
NRF_NFC_2: Q2.2 (S), R4.2, U1.J24 (P0.10/NFC2)
unnamed: AE1.1 (FEED), L3.1
unnamed: C37.2, C38.2, L4.1
unnamed: C40.1, C41.2, L5.1
unnamed: L1.2, L2.1
unnamed: C45.2, Q1.3 (D)
unnamed: C46.2, Q2.3 (D)
unnamed: C33.2, L3.2, U1.H23 (ANT)
unnamed: L1.1, U1.B3 (DCC)
unnamed: C29.1, U1.C1 (DEC1)
unnamed: C28.1, U1.D23 (DEC3)
unnamed: C1.2, U1.AC5 (DECUSB)
unnamed: C24.2, U1.D2 (P0.00/XL1), Y3.2
unnamed: C25.2, U1.F2 (P0.01/XL2), Y3.1
unnamed: TP1.1, U1.AA24 (SWDCLK)
unnamed: TP2.1, U1.AC24 (SWDIO)
unnamed: C23.1, U1.B24 (XC1), Y2.1
unnamed: C22.1, U1.A23 (XC2), Y2.3
unnamed: C10.2, C11.2, U2.24 (AGDC)
unnamed: C16.2, C17.2, U2.7 (VDD_A)
unnamed: C14.2, C15.2, U2.11 (VDD_AM)
unnamed: C18.2, C19.2, U2.3 (VDD_D)
unnamed: C12.2, C13.2, U2.9 (VDD_RF), U2.14 (VDD_DR)
unnamed: C20.2, U2.5 (XTI), Y1.2
unnamed: C21.2, U2.4 (XTO), Y1.4
unnamed: R1.1, USB1.A5 (CC1)
unnamed: R2.1, USB1.B5 (CC2)
RESET: C47.1, R5.2, SW4.1, TP5.1, U1.AC13 (P0.18/NRESET)
SCLK: U1.AC17 (P0.21), U2.30 (SCLK/SCL)
ST_RFI1: C35.1, C36.2, U2.22 (RFI1)
ST_RFI2: C43.2, C44.2, U2.23 (RFI2)
ST_RFO1: L4.2, U2.13 (RFO1)
ST_RFO2: L5.2, U2.15 (RFO2)
VDD3.3v: C2.2, C6.2, C7.2, C30.2, C31.2, C32.2, C34.2, R5.1, TP3.1, U1.A22 (VDD), U1.AD14 (VDD), U1.AD23 (VDD), U1.B1 (VDD), U1.W1 (VDD), U1.Y2 (VDDH), U2.1 (VDD_IO)
vusb: C3.1, C4.2, C5.2, C8.2, C9.2, LED1.1 (VDD), LED2.1 (VDD), U1.AD2 (VBUS), U2.8 (VDD), U2.10 (VDD_TX), USB1.A4B9 (VBUS), USB1.B4A9 (VBUS)

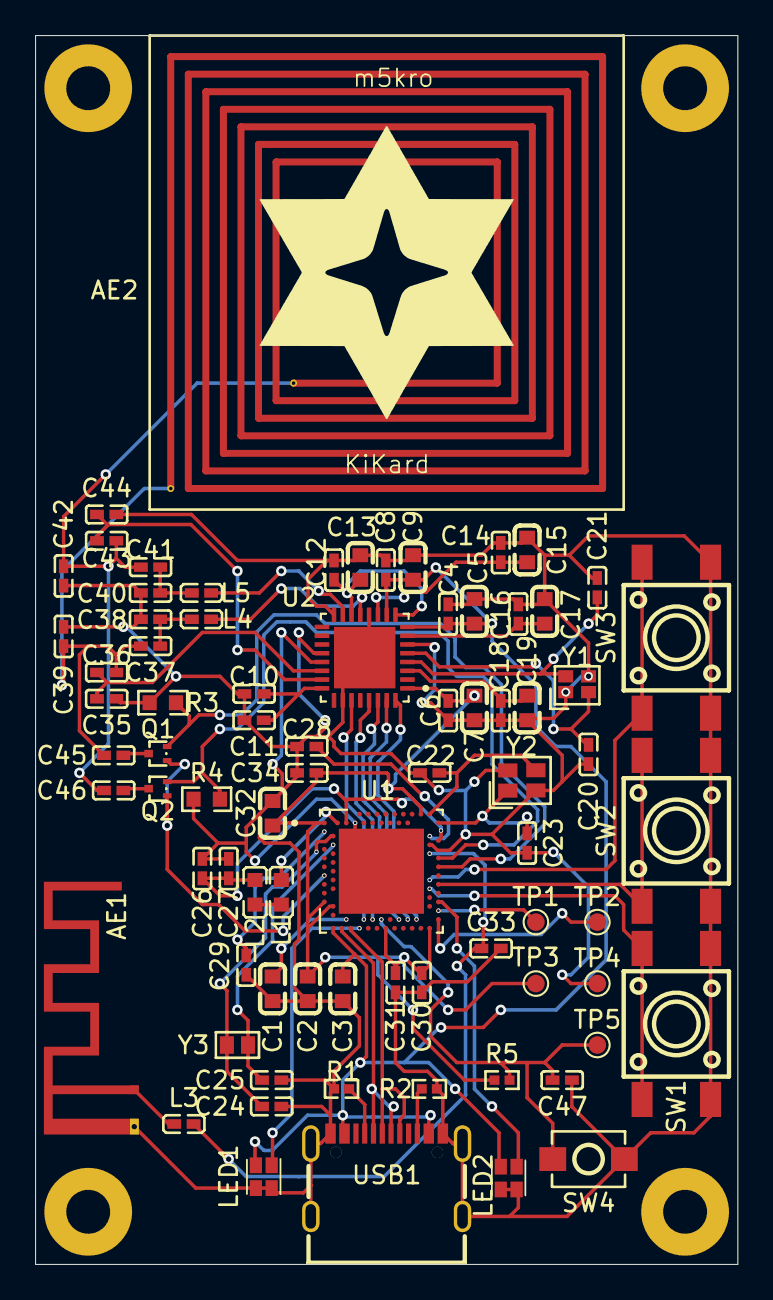
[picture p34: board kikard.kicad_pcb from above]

Board: 2 copper layers, 40.0 x 70.0 mm, 78 parts (0 on the bottom side), 52 nets.

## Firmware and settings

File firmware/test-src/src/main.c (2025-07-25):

/*
 * Copyright (c) 2016 Intel Corporation
 *
 * SPDX-License-Identifier: Apache-2.0
 */

#include <stdio.h>
#include <zephyr/kernel.h>
#include <zephyr/drivers/gpio.h>

/* 1000 msec = 1 sec */
#define SLEEP_TIME_MS   1000

/* The devicetree node identifier for the "led0" alias. */
#define LED0_NODE DT_ALIAS(led1)

/*
 * A build error on this line means your board is unsupported.
 * See the sample documentation for information on how to fix this.
 */
static const struct gpio_dt_spec led = GPIO_DT_SPEC_GET(LED0_NODE, gpios);

int main(void)
{
	int ret;
	bool led_state = true;

	if (!gpio_is_ready_dt(&led)) {
		return 0;
	}

	ret = gpio_pin_configure_dt(&led, GPIO_OUTPUT_ACTIVE);
	if (ret < 0) {
		return 0;
	}

	while (1) {
		ret = gpio_pin_toggle_dt(&led);
		if (ret < 0) {
			return 0;
		}

		led_state = !led_state;
		printf("LED state: %s\n", led_state ? "ON" : "OFF");
		k_msleep(SLEEP_TIME_MS);
	}
	return 0;
}

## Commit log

2025-06-01 Add stuff from KiCad
    [NRF52840-QIAA-R.step, kikard.kicad_pcb, kikard.kicad_sch]
2025-07-25 update BOM
    [BOM.csv, PCB-BOM.csv]
2025-07-25 add schematic pdf
2025-07-25 more rearranging
    [KiKard-Case-Base.stl, KiKard-Case-Top.stl, KiKard-Case.step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]
2025-07-26 Fix BLE ant
    [BOM.csv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]
